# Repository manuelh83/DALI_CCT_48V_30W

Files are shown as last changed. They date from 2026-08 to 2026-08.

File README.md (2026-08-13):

# DALI CCT 48V 30W

DALI-2 DT8 Tunable White LED driver reference design für **48 V DC SELV Eingang** mit bis zu **30 W LED-Leistung**.

Dieses Repository enthält **Hardware- und Firmware-Umfang** inklusive Dokumentation für Entwicklung, Bring-up, Test und Inbetriebnahme.

> ⚠️ **Wichtig:** Referenzdesign für Entwicklungs- und Evaluierungszwecke. Kein automatisch zertifiziertes Endprodukt.

---

## Inhaltsübersicht

- [Projektüberblick](#projektüberblick)
- [Systemarchitektur](#systemarchitektur)
- [Repository-Struktur](#repository-struktur)
- [Hardware-Umfang](#hardware-umfang)
- [Software/Firmware-Umfang](#softwarefirmware-umfang)
- [Toolchain & Voraussetzungen](#toolchain--voraussetzungen)
- [Build & Flash (Firmware)](#build--flash-firmware)
- [Inbetriebnahme (HowTo)](#inbetriebnahme-howto)
- [Test & Verifikation](#test--verifikation)
- [Troubleshooting](#troubleshooting)
- [Sicherheitshinweise](#sicherheitshinweise)
- [Weiterführende Dokumentation](#weiterführende-dokumentation)

---

## Projektüberblick

Das Design realisiert einen DALI-2 DT8 CCT-Treiber (Tunable White) mit:

- **Eingang:** 48 V DC SELV (typischer Bereich 43.2–52.8 V)
- **Ausgang:** gemeinsamer Anodenbus `LED+` und zwei geregelte Kanäle `WW−` / `CW−`
- **Leistung:** bis 30 W
- **Regelung:** kontinuierliche analoge Stromdimmung (0.1–100 %, ohne niederfrequentes PWM-Flackern)
- **Kommunikation:** galvanisch isolierte DALI-2 DT8 Tc Schnittstelle
- **Steuerung:** STM32G031K8T6 + AT24C32E EEPROM

Ziel ist ein robustes Referenzsystem, das als Grundlage für eigene Leuchten-/Treiberentwicklungen dient.

---

## Systemarchitektur

1. **Primärversorgung / Eingangsseite**
   - 48 V SELV Versorgung mit Schutzkonzept für Überspannungsereignisse.

2. **Leistungsteil**
   - 4‑Switch synchroner Buck-Boost (LT8390A) erzeugt geregelten LED-Bus.

3. **LED-Kanalregelung**
   - Zwei lineare Low-Side Konstantstromsenken für Warmweiß/Kaltweiß.

4. **Steuer- und Kommunikationsschicht**
   - STM32G0 übernimmt DALI-Stack, DT8-Verhalten, Kanalmischung, Schutzreaktionen und Persistenz.

5. **Nichtflüchtige Datenhaltung**
   - Externes EEPROM für Parameter, Zustände und Konfigurationswerte.

---

## Repository-Struktur

```text
.
├─ .github/
├─ README.md
├─ firmware/
│  ├─ README.md
│  ├─ docs/
│  │  ├─ README.md
│  │  ├─ build.md
│  │  ├─ api.md
│  │  ├─ dali_implementation.md
│  │  └─ troubleshooting.md
│  ├─ src/
│  ├─ test/
│  └─ lib/
└─ hardware/
   └─ DALI_CCT_48V_30W/
      ├─ README.md
      └─ docs/
         ├─ design-specification.md
         ├─ bom.csv
         ├─ net-class-and-layout-rules.md
         ├─ bring-up-and-test-plan.md
         ├─ open-items-and-risks.md
         └─ firmware-interface.md
```

> Die exakte Dateiliste kann sich weiterentwickeln; für die aktuelle Struktur bitte das Repository-Browsing verwenden.

---

## Hardware-Umfang

Im Pfad `hardware/DALI_CCT_48V_30W/` liegt das vollständige Hardware-Referenzprojekt mit:

- KiCad-Projektdateien (4-Layer PCB, 150 × 60 mm)
- BOM mit Bauteilauswahl und Alternativen
- Spezifikation, Layout-/Netzklassenregeln
- Bring-up-/Testplan
- Risiken & offene Punkte
- Schnittstellendokument zur Firmware-Anbindung

Kernmerkmale:

- 48 V DC SELV Eingang
- 30 W Ausgangsleistung
- gemeinsamer LED+ Bus, getrennte WW/CW Senken
- analoge, kontinuierliche Stromdimmung
- isolierte DALI-2 DT8 Schnittstelle

---

## Software/Firmware-Umfang

Im Pfad `firmware/` befindet sich eine produktionsorientierte Firmware-Basis für **STM32G031** plus host-testbare Logik.

### Enthaltene Bereiche

- `firmware/src/`
  - Hardwareabstraktion/HAL-Wrapper
  - DALI-Kommunikations- und Auswertepfade
  - CCT-/Kanalregel- und Schutzlogik
  - NVM-Zugriffe (EEPROM)
  - Scheduler/Task-Orchestrierung

- `firmware/test/`
  - Host-seitige Unit-Tests für zentrale Protokoll-/Regellogik

- `firmware/docs/`
  - `build.md` (Build/Flash)
  - `api.md` (Modul-/API-Überblick)
  - `dali_implementation.md` (DT8-Verhalten)
  - `troubleshooting.md` (Fehlersuche)

- `firmware/lib/`
  - Integrationshaken für STM32CubeG0 bzw. plattformnahe Komponenten

### Firmware-Funktionsumfang (auf hoher Ebene)

- DALI-2/DT8 Kommandopfad
- Helligkeits- und CCT-bezogene Sollwertverarbeitung
- Kanalmischung WW/CW gemäß Zieltemperatur/Farbanteil
- Schutz- und Fehlerbehandlung (z. B. Grenzwertverletzungen)
- Persistenz relevanter Parameter im EEPROM

---

## Toolchain & Voraussetzungen

### Hardware

- Labornetzteil 48 V DC mit Strombegrenzung
- Last (geeignetes CCT-LED-Setup)
- DALI-Master / DALI-USB Interface
- Multimeter, optional Oszilloskop und Thermalkamera

### Software/Firmware

- ARM GCC Toolchain (oder projektspezifisch dokumentierte Alternative)
- Build-System gemäß `firmware/docs/build.md`
- Flash/Debug-Tool für STM32G0
- Optional: Host-Testumgebung (Compiler + Testframework laut `firmware/test`)

---

## Build & Flash (Firmware)

> Verbindliche Details stehen in `firmware/docs/build.md`.

Typischer Ablauf:

1. Toolchain installieren
2. Firmware-Projekt konfigurieren
3. Build erzeugen (Debug/Release)
4. Binary/ELF auf STM32G031 flashen
5. Serielles Logging / Debug-Schnittstelle prüfen
6. Basisfunktion ohne DALI-Verkehr verifizieren

Empfehlung:

- Erst mit konservativen Strom-/Leistungsgrenzen testen
- Schutzpfade und Fault-Indikationen früh validieren

---

## Inbetriebnahme (HowTo)

Diese Schrittfolge ist als praxisorientierter Leitfaden gedacht und ergänzt den detaillierten Bring-up-Plan unter `hardware/.../docs/bring-up-and-test-plan.md`.

### 1) Sichtprüfung (ohne Spannung)

- Bestückung, Polaritäten, Lötqualität, Steckverbinder prüfen
- Isolations- und Kriechstrecken visuell kontrollieren
- Sicherstellen, dass keine Kurzschlüsse zwischen kritischen Netzen vorliegen

### 2) Erstes Einschalten (ohne LED-Last)

- Labornetzteil auf 48 V setzen, Stromlimit niedrig starten
- Board versorgen und Ruhestrom plausibilisieren
- Grundversorgungen (MCU-Rails, Referenzen) messen

### 3) Firmware laden und Basiskommunikation testen

- Firmware flashen
- MCU startet ohne Fault-Latch
- Debug/Statusausgaben oder definierte Lebenszeichen prüfen

### 4) DALI-Bus anbinden

- DALI-Leitungen korrekt verbinden (Polarität/Buskonzept beachten)
- DALI-Master verbinden
- Erreichbarkeit und Reaktion auf Basisbefehle verifizieren

### 5) LED-Last anschließen

- CCT-Last korrekt an `LED+`, `WW−`, `CW−` anschließen
- Mit niedrigen Sollwerten starten
- Kanalströme messen und plausibilisieren

### 6) Funktionsprüfung CCT/Helligkeit

- Helligkeitsrampe über den vorgesehenen Bereich prüfen
- CCT-Änderungen (warm ↔ kalt) beobachten
- Übergänge auf Stabilität/Flickerfreiheit prüfen

### 7) Schutz- und Grenzfalltests

- Grenzbereiche in kontrollierter Form anfahren
- Verifikation von Fault-Reaktionen und Recovery-Strategie
- Sicherstellen, dass keine unzulässige Überlastung entsteht

### 8) Thermik-Check unter Dauerlast

- Erwärmung an kritischen Komponenten überwachen
- Betriebspunkt nur freigeben, wenn thermisch stabil

### 9) Persistenz/NVM prüfen

- Relevante Parameter ändern
- Power-Cycle durchführen
- Wiederherstellung aus EEPROM verifizieren

### 10) Abschlussfreigabe (Prototyp)

- Dokumentierte Sollwerte/Abnahmekriterien abgleichen
- Messergebnisse protokollieren

---

## Test & Verifikation

Empfohlene Reihenfolge:

1. Host-Unit-Tests (`firmware/test`)
2. Kommunikationspfad DALI/DT8
3. Kanalregelung und CCT-Verhalten
4. Fault-Injection / Schutzpfade
5. Thermik- und Dauerlasttests

Für formale Kriterien den hardwareseitigen Bring-up/Testplan verwenden.

---

## Troubleshooting

- Kein Start nach Flash:
  - Takt-/Reset-Konfiguration und Build-Target prüfen
  - Versorgung und Brownout-Bedingungen verifizieren

- DALI ohne Reaktion:
  - Busverdrahtung und Master-Konfiguration kontrollieren
  - Implementierte DT8-Kommandos mit `firmware/docs/dali_implementation.md` abgleichen

- Instabiles Dimmverhalten:
  - Sollwertgrenzen und Kalibrierungen prüfen
  - Kanalströme und Lastkompatibilität messen

- Unerwartete Faults:
  - Schutzschwellen/Telemetrie sichten
  - Schritte aus `firmware/docs/troubleshooting.md` anwenden

---

## Sicherheitshinweise

- Nur durch qualifiziertes Fachpersonal in geeigneter Laborumgebung betreiben
- Strombegrenzung beim Erststart immer aktivieren
- Thermische Risiken bei Dauerlast berücksichtigen
- Isolations- und EMV-Anforderungen für Zielprodukt separat validieren

---

## Weiterführende Dokumentation

### Root

- `README.md` (dieses Dokument)

### Hardware

- `hardware/DALI_CCT_48V_30W/README.md`
- `hardware/DALI_CCT_48V_30W/docs/design-specification.md`
- `hardware/DALI_CCT_48V_30W/docs/bom.csv`
- `hardware/DALI_CCT_48V_30W/docs/net-class-and-layout-rules.md`
- `hardware/DALI_CCT_48V_30W/docs/bring-up-and-test-plan.md`
- `hardware/DALI_CCT_48V_30W/docs/open-items-and-risks.md`
- `hardware/DALI_CCT_48V_30W/docs/firmware-interface.md`

### Firmware

- `firmware/README.md`
- `firmware/docs/README.md`
- `firmware/docs/build.md`
- `firmware/docs/api.md`
- `firmware/docs/dali_implementation.md`
- `firmware/docs/troubleshooting.md`

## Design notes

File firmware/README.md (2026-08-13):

# Firmware

Production-oriented STM32G031 firmware skeleton and host-testable logic for the DALI CCT 48V 30W reference design.

## Contents

- `src/` – HAL wrappers, DALI stack, control logic, NVM, protection, scheduler
- `test/` – host-side unit tests for the critical control and parser logic
- `docs/` – build, API, DALI, and troubleshooting notes
- `lib/` – optional STM32CubeG0 integration hook

See `docs/build.md` for build and flash instructions.

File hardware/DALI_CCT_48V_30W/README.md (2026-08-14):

# DALI CCT 48V 30W – Hardware Reference Design Rev A

> **⚠️ WARNING – REFERENCE DESIGN ONLY**
>
> This is an engineering reference design. It **must not be manufactured or deployed** without:
> - Independent schematic review and simulation
> - Prototype build and validation
> - Thermal design verification
> - EMC testing per applicable standards (e.g., EN 55015 / CISPR 15)
> - Electrical safety assessment (e.g., IEC 62368-1 / EN 61347-2-13)
> - DALI-2 conformance testing (DIIA/DALI Alliance test suites)
> - All applicable regulatory approvals for target market

---

## Project Scope

A production-oriented KiCad 8+ reference design for a **48 V SELV, 30 W maximum, DALI-2 DT8 Tunable White LED driver** with the following key features:

| Parameter | Value |
|---|---|
| Input voltage | 48 V DC SELV, operating range 43.2–52.8 V |
| Transient protection | Designed for short transients up to 60 V |
| LED output | 30 W max total; three terminals LED+, WW−, CW− (common-anode CCT) |
| LED string range | 28–42 V per channel |
| Max current per channel | 700 mA (firmware limits total power to ≤30 W) |
| Dimming | 0.1–100%, continuous/analog current control, no low-frequency PWM |
| DALI | DALI-2 control gear, DT8 Tc Tunable White (IEC 62386-101/-102/-209) |
| PCB size | 150 × 60 mm, 4 layers |
| Component height | ≤30 mm |
| Thermal | Aluminium enclosure coupling via B.Cu thermal zone + thermal vias |

---

## Architecture

```
48V DC SELV IN
    │
    ├── [J1] 48V_IN+/48V_IN− screw terminal (5.08mm)
    │
    ├── BLOCK 1: Input Protection
    │     F1: Fuse 1A slow-blow
    │     D1: P-channel MOSFET reverse-polarity protection
    │     TV1: TVS 60V/600W bidirectional clamp
    │     C1,C2: 100µF/63V bulk caps + EMI filter
    │
    ├── BLOCK 4: Auxiliary Supply 48V→5V→3.3V
    │     U_AUX1: LMR16006YDDAR synchronous buck (5V/600mA)
    │     U_LDO: AP2112K-3.3 LDO (3.3V/600mA)
    │
    ├── BLOCK 2: 4-Switch Synchronous Buck-Boost LED Bus
    │     U_BB: LT8390A controller, Q1-Q4 MOSFETs, L2 47µH
    │     Output: LED_BUS+ nominally 44V
    │     → [J3-pin1] LED+ (common anode)
    │
    ├── BLOCK 3: Two Linear Low-Side Current Sinks
    │     Q_WW + R_SENSE_WW + U_CS_WW (OPA2333) → [J3-pin2] WW−
    │     Q_CW + R_SENSE_CW + U_CS_CW (OPA2333) → [J3-pin3] CW−
    │     Hardware OCP via LM393 comparator (threshold ~900mA)
    │     Analog current setpoint from MCU DAC (MCP4728 12-bit I2C)
    │
    ├── BLOCK 5: MCU, NVM, SWD
    │     U_MCU: STM32G031K8T6 (ARM Cortex-M0+, 64KB flash)
    │     U_EEP: AT24C32E I2C EEPROM (DALI NVM)
    │     U_DAC: MCP4728 12-bit quad DAC (current setpoints)
    │     [J4] SWD programming header (1.27mm)
    │
    └── BLOCK 6: Galvanically Isolated DALI Interface
          Isolation goal: 2.5kVrms (subject to safety standard review)
          U_DALI: NXP UBA2015 or optocoupler-based frontend
          D_ESD: PRTR5V0U2X ESD protection
          [J2] DALI_A/DALI_B screw terminal (5.08mm)
```

### Power Architecture Note

This design uses a **common regulated 4-switch synchronous buck-boost LED bus** (nominally 44 V) followed by **two independently controlled, linear low-side constant-current sinks** (WW and CW). This is the correct representation: a single regulated voltage bus with common LED anode, and individual current control on the low side per channel.

---

## Opening in KiCad 8+

1. Open KiCad 8.0 or later.
2. File → Open Project → select `DALI_CCT_48V_30W.kicad_pro`.
3. Open the schematic editor: `DALI_CCT_48V_30W.kicad_sch`.
4. Open the PCB editor: `DALI_CCT_48V_30W.kicad_pcb`.

### ERC/DRC Status (Rev A.1)

**Schematic (`.kicad_sch`):** All KiCad symbol instances required for the current reference design are present, and U_BB now uses the exact project-local `AnalogDevices:LT8390AIFE` 28-pin symbol instead of the generic `Device:IC`. The schematic netlist is still intended to be verified with KiCad 8 ERC after opening the project locally. See OI-011 in `docs/open-items-and-risks.md` for full details.

**PCB (`.kicad_pcb`):**
- Board outline, mounting holes, and connector footprints defined (Rev A)
- **Rev A.1 additions**: D2PAK footprints for Q_WW and Q_CW with 9 thermal vias each and 20×20mm B.Cu thermal pour zones
- Isolation barrier silkscreen updated: `ISO BARRIER: CLR>=2mm / CRG>=5mm / ZONE=8mm (IEC 62368-1:2018)`
- Full component placement and routing requires KiCad 8 GUI after netlist import from schematic

**Intentional open items / known DRC status:**
- Routing is incomplete; ratsnest will show unconnected nets after netlist import
- Q_WW/Q_CW D2PAK gate pads are unconnected pending netlist import (expected)
- Other complex ICs still use generic `Device:IC` symbols — replace them with exact library symbols in follow-up cleanup work
- Full DRC pass (including creepage/clearance checks for `DALI_ISO` net class) requires complete routing

**Normative DRC rules (`.kicad_dru`):**
- `DALI_ISO` class: clearance ≥ 2.0mm (IEC 62368-1:2018 Table G.8), keepout zone ≥ 8mm (satisfies creepage ≥ 5.0mm with margin)
- `PWR_HV` (48V): clearance ≥ 0.5mm, track width ≥ 2.0mm
- `PWR_LED` (LED bus): track width ≥ 1.5mm
- `KELVIN` (sense): track width ≤ 0.2mm, Kelvin-pair routing required

See `docs/open-items-and-risks.md` for full list of open items (OI-011: RESOLVED, OI-012: IN PROGRESS).

---

## Directory Structure

```
hardware/DALI_CCT_48V_30W/
├── DALI_CCT_48V_30W.kicad_pro      KiCad 8 project file
├── DALI_CCT_48V_30W.kicad_sch      Schematic (functional block descriptions + net list)
├── DALI_CCT_48V_30W.kicad_pcb      PCB layout (board outline, layer setup, key placements)
├── README.md                        This file
└── docs/
    ├── design-specification.md      Full electrical specification
    ├── bom.csv                      Bill of Materials
    ├── net-class-and-layout-rules.md  PCB routing rules and net classes
    ├── bring-up-and-test-plan.md    Prototype bring-up sequence
    ├── open-items-and-risks.md      Open design items and risks
    └── firmware-interface.md        MCU/firmware interface documentation
```

---

## Practical Power and Current Limits

| Condition | WW Current | CW Current | Total Power |
|---|---|---|---|
| Full warm white (2700K) | 700 mA | 0 mA | ≤28 W at 40V LED |
| Full cool white (6500K) | 0 mA | 700 mA | ≤28 W at 40V LED |
| Neutral white (4000K) | ~350 mA | ~350 mA | ≤25 W typical |
| Firmware hard limit | | | 30 W total |
| Hardware OCP per channel | 1.05 A | 1.05 A | — |

The firmware enforces `P_total = V_LED_BUS × (I_WW + I_CW) ≤ 30 W` using ADC-measured bus voltage and DAC-controlled current.

---

## License / Disclaimer

This reference design is provided as-is for engineering reference purposes only. No warranty of fitness for any purpose is expressed or implied. The designer and contributors accept no liability for any direct or indirect damages arising from use of this material. All component datasheets, safety standards, and certification requirements must be independently verified by a qualified engineer before manufacture.

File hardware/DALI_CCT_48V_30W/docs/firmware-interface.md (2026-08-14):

# Firmware Interface Documentation – DALI CCT 48V 30W Rev A

---

## 1. Overview

The firmware runs on a STM32G031K8T6 (ARM Cortex-M0+, 64MHz, 64KB flash, 8KB SRAM). It implements:

- DALI-2 control gear behavior (IEC 62386-101 and -102)
- DALI-2 Device Type 8 – Tunable White Tc (IEC 62386-209)
- Analog current control of two LED channels (WW and CW) via I2C DAC (MCP4728)
- NVM management via I2C EEPROM (AT24C32E)
- Hardware fault monitoring and protection
- Thermal management via NTC ADC

---

## 2. MCU Pin Roles

| Pin | Direction | Net | Function | Notes |
|---|---|---|---|---|
| PA0 | ADC in | ADC_NTC | NTC temperature sense | 12-bit ADC; divider: 100kΩ pull-up to 3.3V, NTC to GND |
| PA1 | ADC in | ADC_VIN | 48V input voltage monitor | Divider: 750kΩ / 38.3kΩ → ~0.048×Vin |
| PA2 | ADC in | ADC_VBUS | LED bus voltage monitor | Divider: 750kΩ / 38.3kΩ → ~0.048×Vbus |
| PA4 | DAC out | MCU_DAC_WW | WW current setpoint (backup) | 12-bit DAC; only used if MCP4728 I2C fails |
| PA5 | DAC out | MCU_DAC_CW | CW current setpoint (backup) | 12-bit DAC backup |
| PA6 | GPIO in | OCP_WW | WW over-current latch signal | Active-high from LM393 comparator |
| PA7 | GPIO in | OCP_CW | CW over-current latch signal | Active-high from LM393 comparator |
| PA9 | USART1_TX | DALI_TX | DALI transmit (to optocoupler) | Half-duplex; open-drain recommended |
| PA10 | USART1_RX | DALI_RX | DALI receive (from optocoupler) | Pull-up to 3.3V |
| PA13 | SWD | SWDIO | SWD data line | Programming and debug |
| PA14 | SWD | SWDCLK | SWD clock | Programming and debug |
| PB0 | GPIO out | EN_WW | WW channel enable | Active-high; drives NAND latch for Q_WW gate |
| PB1 | GPIO out | EN_CW | CW channel enable | Active-high |
| PB3 | GPIO out | LED_STATUS | Green status LED | Active-high; 1kΩ series |
| PB4 | GPIO out | LED_FAULT | Red fault LED | Active-high; 1kΩ series |
| PB6 | I2C1_SCL | I2C_SCL | I2C bus clock | 400kHz; 4.7kΩ pull-up to 3.3V |
| PB7 | I2C1_SDA | I2C_SDA | I2C bus data | 400kHz; 4.7kΩ pull-up to 3.3V |
| PB8 | GPIO out | BB_SHDN | Buck-boost enable/shutdown | Active-low shutdown; 100kΩ pull-up to 5V_AUX keeps converter enabled when MCU is high-Z |
| NRST | Reset | NRST | Hardware reset | 100nF to GND; external reset pin |

### I2C Device Addresses

| Device | I2C Address | Function |
|---|---|---|
| MCP4728 | 0x60 | 12-bit quad DAC for WW/CW setpoints |
| AT24C32E | 0x50 | EEPROM for DALI NVM |

**LT8390A hardware-set analog pins**

`RT`, `SLOPE`, `ITH/COMP`, `CS+`, `CS-`, and `FB` are not firmware-controlled. Their values are fixed in hardware by `R_RT`, `R_SLOPE`, `C_ITH`, `R_ITH`, `C_ITH2`, `R_FB1`, and `R_FB2`. Firmware only asserts `BB_SHDN`, monitors `ADC_VIN` / `ADC_VBUS`, and reacts to resulting faults.

---

## 3. DALI Protocol Implementation

### 3.1 Standards Targeted

| Standard | Scope |
|---|---|
| IEC 62386-101 | DALI-2 general requirements, electrical interface |
| IEC 62386-102 | Control gear (slave) general behavior |
| IEC 62386-209 | Device type 8: colour control (Tunable White Tc) |

**Note**: DALI-2 certification is not claimed. The firmware is designed to follow the above standards but must pass official DALI Alliance test suites before the product may be labeled as DALI-2 certified.

### 3.2 DALI Physical Layer

- Baud rate: 1200 baud (Manchester encoding)
- Bit period: 833µs; half-bit period: 416µs
- Bus voltage: 9.5V–22.5V (sourced by DALI master)
- Transmission: MCU drives optocoupler TX open-collector pull-down
- Reception: optocoupler RX drives MCU PA10 (USART1_RX)
- USART configuration: 1200 baud, 8N1, single-wire half-duplex mode; Manchester coding implemented in software via bit-banging on TIM1 or via hardware USART in Manchester mode (STM32G0 supports hardware Manchester)

### 3.3 DALI Device Behavior (IEC 62386-102)

The firmware must implement the following command sets:

**Addressing and Initialization**
- INITIALISE, RANDOMISE, COMPARE, WITHDRAW, SEARCH ADDRESS, PROGRAM SHORT ADDRESS, VERIFY SHORT ADDRESS, QUERY SHORT ADDRESS
- Support for broadcast, group, and individual short address

**Arc Power Level Control**
- DAPC (Direct Arc Power Control): 0–254 arc-power levels
- ON, OFF, RECALL MAX LEVEL, RECALL MIN LEVEL, STEP UP, STEP DOWN
- GO TO SCENE (16 scenes: 0–15)
- SET MAX LEVEL, SET MIN LEVEL, SET SYSTEM FAILURE LEVEL, SET POWER ON LEVEL
- Fade: FADE TIME (0–15), FADE RATE (1–15), NON-FADE TIME
- QUERY commands: QUERY STATUS, QUERY CONTROL GEAR PRESENT, QUERY LIGHT SOURCE, QUERY ACTUAL LEVEL, QUERY MAX/MIN/POWER-ON/SYSTEM-FAILURE LEVEL, QUERY FADE TIME/RATE, QUERY SCENE LEVEL

**DALI Arc-Power Dimming Curve**:
```
If arc_power_level == 0: output = OFF (current = 0)
If arc_power_level == 1: output = MIN_LEVEL (firmware default: ~0.1% = ~0.6mA at 600mA FSR)
If arc_power_level == 254: output = MAX_LEVEL (firmware default: 100% = full current)
Physical_current = max_current × (10 ^ ((arc_power_level - 254) / 253 × log10(min/max)))
```
The logarithmic curve maps 254 steps across a configurable dimming range.

### 3.4 DT8 Tc Implementation (IEC 62386-209)

**Colour Temperature Control**

Commands implemented:
- SET COLOUR TEMPERATURE TC (value in mirek = 1,000,000 / Kelvin)
- QUERY COLOUR VALUE: Colour Temperature TC (current and target)
- QUERY COLOUR TEMPERATURE TC COOLEST, QUERY COLOUR TEMPERATURE TC WARMEST
- SET COLOUR TEMPERATURE TC COOL BOUND, SET COLOUR TEMPERATURE TC WARM BOUND

Default Tc range: 153 mirek (6536K) to 370 mirek (2703K). Configurable via NVM.

**WW/CW Mixing Algorithm**

Given a target colour temperature Tc_target and a total current I_total derived from arc-power level:

```c
// Normalise: 0.0 = coolest (Tc_cool), 1.0 = warmest (Tc_warm)
float alpha = (Tc_target - Tc_cool) / (Tc_warm - Tc_cool);
alpha = clamp(alpha, 0.0f, 1.0f);

// Linear mix (default; replace with calibrated table for accuracy — see OI-009)
float I_WW = I_total * alpha;
float I_CW = I_total * (1.0f - alpha);

// Power limit enforcement
float v_bus = adc_to_volts(ADC_VBUS);
float p_est = v_bus * (I_WW + I_CW);
if (p_est > P_MAX_LIMIT) {
    float scale = P_MAX_LIMIT / p_est;
    I_WW *= scale;
    I_CW *= scale;
}
```

**Calibrated mixing table (production implementation):**

For accurate CCT control, the linear approximation above should be replaced with a calibrated lookup table derived from photometric measurement of the actual LED module. The calibration procedure is:

1. Measure CIE 1931 (x, y) chromaticity of WW LED at 100 %, 50 %, 10 % current; record lm/mA.
2. Measure CIE 1931 (x, y) chromaticity of CW LED at 100 %, 50 %, 10 % current; record lm/mA.
3. For each target Tc in the operating range (e.g., every 100 mirek), solve the 2-primary mixing equations:

```
x_mix = (I_WW × lm_WW × x_WW + I_CW × lm_CW × x_CW) / (I_WW × lm_WW + I_CW × lm_CW)
y_mix = (I_WW × lm_WW × y_WW + I_CW × lm_CW × y_CW) / (I_WW × lm_WW + I_CW × lm_CW)
```

   Subject to: x_mix, y_mix lie on the Planckian locus at the target Tc.

4. Build a lookup table: `uint16_t ww_ratio_table[TC_STEPS]` where the value represents I_WW / I_total × 4095.
5. Store lookup table in MCU flash. At runtime, interpolate linearly between table entries.
6. Verify gamut: confirm the LED pair can achieve all Tc values in [Tc_cool, Tc_warm]; document the achievable gamut.

```c
// Production mixing with lookup table
uint16_t idx     = tc_to_table_index(Tc_target);     // mirek → table index
float    ratio   = ww_ratio_table[idx] / 4095.0f;    // WW fraction
float    I_WW    = I_total * ratio;
float    I_CW    = I_total * (1.0f - ratio);
```

**Note**: Linear interpolation assumes equal efficacy per mA for WW and CW. Real LEDs differ in lumens/mA and correlated colour temperature vs. current. The calibrated lookup table is recommended for production.

---

## 4. NVM Behavior (EEPROM AT24C32E)

### 4.1 DALI NVM Requirements

The following parameters must be stored in non-volatile memory per IEC 62386-102/-209:

| Parameter | Size | Default |
|---|---|---|
| Short address | 1 byte | 0xFF (unassigned) |
| Group membership (groups 0–15) | 2 bytes | 0x0000 |
| Scene table: dim levels (16 × 1 byte) | 16 bytes | 0xFF (MASK = no action) |
| Scene table: CCT values (16 × 2 bytes) | 32 bytes | 0x0000 (no-change) |
| MAX LEVEL | 1 byte | 0xFE (254) |
| MIN LEVEL | 1 byte | 0x01 (1) |
| POWER ON LEVEL | 1 byte | 0xFF (LAST ACTIVE) |
| SYSTEM FAILURE LEVEL | 1 byte | 0xFF (LAST ACTIVE) |
| FADE TIME | 1 byte | 0 (no fade) |
| FADE RATE | 1 byte | 7 |
| Physical min level | 1 byte | 0x01 |
| Device type | 1 byte | 0x08 (DT8) |
| Tc cool bound (mirek) | 2 bytes | 153 |
| Tc warm bound (mirek) | 2 bytes | 370 |
| Last active arc-power level | 1 byte | 0xFE |
| Last active Tc (mirek) | 2 bytes | 261 (3831K neutral) |

Total static NVM: ~70 bytes. With wear-leveling overhead, allocate 512 bytes minimum.

### 4.2 Wear-Leveling Strategy

- Static DALI config (address, groups, scenes): written only on explicit DALI write commands. Expected: < 1000 writes per lifetime. No wear-leveling needed; write to fixed page.
- Dynamic state (last arc-power, last Tc): written on state change after a 5-second debounce timer. Circular buffer of 64 slots × 4 bytes = 256 bytes. Rotates write pointer on each write.
  - At 1M page-write endurance per slot × 64 slots = 64M writes before wear-out
  - At worst case 10 writes/hour × 8760 hours/year = 87,600 writes/year → >730 years effective life
- Firmware reads back NVM after write and verifies correctness (read-after-write check).

### 4.3 Power-On State Restoration

On power-up:
1. Read POWER ON LEVEL from NVM.
2. If POWER ON LEVEL == 0xFF (LAST ACTIVE): read last-active dim level and Tc from circular buffer.
3. Ramp outputs from 0 to target values over FADE TIME (if non-zero).
4. If NVM read fails (I2C error, CRC fail): use firmware-compiled defaults (50% dim, 4000K).

On DALI bus loss (no valid DALI frame received for >500ms):
- Maintain current output without change.
- Set "LAMP FAILURE" status bit (query will return it cleared once bus resumes).

---

## 5. Brightness and CCT to WW/CW Current Mapping

### 5.1 Current Scale

- Maximum hardware current per channel: 900 mA (OCP threshold)
- Maximum firmware-enforced current per channel: **600 mA** (firmware constant `I_MAX = 600mA`)
- Maximum total firmware-enforced power: firmware enforces P_total ≤ 28W
- DAC full scale: MCP4728 = 4096 counts → 0–1.0V → 0–600mA through op-amp control loop

```
DAC_WW_code = round(I_WW_target / I_MAX * 4095)
DAC_CW_code = round(I_CW_target / I_MAX * 4095)
```

Where `I_MAX = 600mA` (firmware constant; hardware OCP set to 900mA absolute limit).

### 5.2 Power Limiting

The bus voltage is fixed at 44 V (LT8390A setpoint; not adjusted by firmware). Power limiting is enforced by capping total current:

```c
// Fixed bus voltage: no ADC_VBUS monitoring for adaptive control
const float V_BUS_FIXED = 44.0f;   // V; fixed by hardware feedback divider
const float P_MAX_LIMIT = 28.0f;   // W; 28W leaves headroom below 30W spec

float p_est = V_BUS_FIXED * (i_ww_set + i_cw_set);
if (p_est > P_MAX_LIMIT) {
    float scale = P_MAX_LIMIT / p_est;
    i_ww_set *= scale;
    i_cw_set *= scale;
}
```

ADC_VBUS (PA2) is still read for monitoring and fault detection (over/under-voltage), but is **not** used to adjust the bus voltage setpoint. The LT8390A feedback divider fixes V_bus at 44 V.

### 5.3 Fade Implementation

DALI fade timer runs at 100Hz (every 10ms). On each tick during a fade:

```
target_arc = commanded arc-power level
target_tc  = commanded Tc

// Dimming fade
if (current_arc != target_arc):
    step = fade_step_per_tick(fade_time)    // from DALI fade table
    current_arc = approach(current_arc, target_arc, step)

// Tc fade (simultaneous with dimming fade)
if (current_tc != target_tc):
    tc_step = fade_step_per_tick(fade_time)
    current_tc = approach(current_tc, target_tc, tc_step)

// Compute and update DAC
update_currents(current_arc, current_tc)
```

Fade occurs simultaneously for arc-power and colour temperature.

### 5.4 Minimum Dimming Level Analysis (OI-010)

The specification requires 0.1 % dimming (1:1000 ratio), corresponding to 0.7 mA at 700 mA full scale.

**Error budget at minimum current:**

| Error source | Value | Current error at 100 mΩ sense |
|---|---|---|
| OPA2333 input offset (max, 25°C) | 10 µV | 0.10 mA |
| OPA2333 input offset drift (max, −40 to +85°C) | 0.05 µV/°C × 60°C | +0.03 mA |
| MCP4728 zero-code output (max) | 0.5 mV | 5.0 mA |
| MCP4728 INL (max, 12-bit) | 2 LSB = 0.488 mV | 0.49 mA |
| PCB leakage / sense resistor offset | < 10 µV | < 0.10 mA |
| **Total (worst-case, RSS)** | | **≈ 5.1 mA** |

The dominant error is the **MCP4728 zero-code offset** (~0.5 mV at DAC output = 0). The offset is trimmed per device; typical offset is < 0.1 mV.

**Achievable minimum current (typical):** 0.7 mA (MCP4728 typical offset 0.1 mV → 1 mA total error; firmware zeros DAC and cuts EN_WW/EN_CW to achieve true off below 0.5 mA).

**Mitigation for worst-case parts:**
1. **Firmware offset compensation**: At start-up, characterise per-unit DAC offset by measuring V_SENSE at DAC code 0 with channel enabled; store correction in NVM; subtract from all DAC codes.
2. **Dual-range option (if 0.1 % not achievable)**: Below arc-power level 10 (≈ 1 %), enable PWM blanking: pulse EN_WW/EN_CW at 1 kHz with duty cycle proportional to dim level. This extends effective range to 1:10 000. Ensure PWM frequency ≥ 1 kHz to avoid visible flicker.
3. **Sense resistor increase**: Replacing 100 mΩ with 200 mΩ halves the offset-referred error at cost of 2× higher minimum voltage drop (140 mV at 700 mA); acceptable if MOSFET Vds headroom permits.

**Recommendation**: Implement firmware offset compensation (option 1) first; evaluate on prototype. Dual-range PWM (option 2) is a fallback if offset compensation is insufficient at temperature extremes.

---

## 6. Fault Handling

### 6.1 Fault Types

| Fault | Detection | Action | Recovery |
|---|---|---|---|
| OCP WW channel | PA6 high (LM393) | EN_WW = 0 immediately; log fault; set LAMP FAILURE | MCU resets after 100ms; 3 retry attempts; permanent off after 3 fails |
| OCP CW channel | PA7 high (LM393) | EN_CW = 0 immediately; log fault | Same as WW |
| Over-temperature warn (70°C) | ADC_NTC > threshold | Reduce I_MAX by 20% (600mA → 480mA); set LED_FAULT blink pattern | Auto-clear when temp < 60°C |
| Over-temperature shutdown (85°C) | ADC_NTC > threshold | EN_WW = 0; EN_CW = 0; BB_SHDN = 0; LED_FAULT solid | Auto-restart when temp < 75°C |
| Input under-voltage (<43V) | ADC_VIN < threshold | BB_SHDN = 0 (shutdown converter); channels off | Auto-enable when Vin > 44V |
| Input over-voltage (>55V) | ADC_VIN > threshold | BB_SHDN = 0 immediately | Auto-enable when Vin < 53V |
| I2C DAC failure | I2C NACK from MCP4728 | Switch to MCU internal DAC (PA4/PA5); log fault | Retry I2C init on next power cycle |
| NVM read failure | I2C NACK or CRC fail | Use defaults; log fault; LED_FAULT blink | Retry on power cycle |

#### NTC-based Current Limiting (Thermal Management)

The NTC thermistor (NTC1, 100kΩ B3950, mounted near Q_WW/Q_CW on B.Cu thermal pour) is read via ADC_NTC (PA0) every 500 ms. Current limiting is purely **current-based** – the bus voltage (44 V fixed) is never adjusted by firmware.

```c
// Thermal current-limiting state machine (no Vbus modification)
float pcb_temp_c = ntc_adc_to_celsius(adc_read(ADC_NTC));

if (pcb_temp_c >= NTC_SHUTDOWN_TEMP) {       // 85°C
    i_max_thermal = 0.0f;                    // total shutdown
    set_fault(FAULT_OVERTEMP_SHUTDOWN);
} else if (pcb_temp_c >= NTC_WARN_TEMP) {    // 70°C
    i_max_thermal = I_MAX_NOMINAL * 0.80f;   // 600mA × 0.80 = 480mA
    set_fault(FAULT_OVERTEMP_WARN);
} else if (pcb_temp_c < NTC_WARN_TEMP - NTC_HYSTERESIS) {  // < 60°C
    i_max_thermal = I_MAX_NOMINAL;           // 600mA; normal operation
    clear_fault(FAULT_OVERTEMP_WARN);
}

// Apply thermal limit before DAC update
float i_ww_clamped = fminf(i_ww_set, i_max_thermal);
float i_cw_clamped = fminf(i_cw_set, i_max_thermal);
```

**Key constants:**
- `I_MAX_NOMINAL = 600mA` – firmware maximum under normal conditions
- `NTC_WARN_TEMP = 70°C` – triggers 20% current reduction
- `NTC_SHUTDOWN_TEMP = 85°C` – triggers full shutdown
- `NTC_HYSTERESIS = 10°C` – re-enable hysteresis (warn clears at 60°C, shutdown at 75°C)

**Important**: This is purely current-limiting. The firmware does **not** read `ADC_VBUS` to adjust the LT8390A output voltage. The bus remains at a fixed 44 V at all times.

### 6.2 DALI Fault Reporting

The DALI QUERY STATUS command returns:
- Bit 0: Ballast failure (set if hardware fault prevents operation)
- Bit 1: Lamp failure (set if LED OCP latch is active)
- Bit 2: Lamp arc power on (set if arc-power > 0)
- Bit 3: Limit error (set if requested level was clipped by MIN or MAX)
- Bit 4: Fade running
- Bit 5: Reset state (set after power-on before any DALI command received)
- Bit 6: Missing short address
- Bit 7: Power failure (set after unexpected power-off detected via NVM)

---

## 7. Test and Programming Interface

### 7.1 SWD Interface (J4)

| Pin | Signal | Notes |
|---|---|---|
| 1 | GND | Reference |
| 2 | SWDIO | SWD data; also TP_SWDIO test pad |
| 3 | SWDCLK | SWD clock; also TP_SWDCLK test pad |
| 4 | 3.3V | Target VCC (powered by board) |

Compatible debuggers: ST-LINK V2, ST-LINK V3, J-Link, CMSIS-DAP.
Connector: 1.27mm pitch 4-pin (e.g., Samtec FTSH-104-01-L-DV) or solder pads.

### 7.2 Factory Test Procedure

1. Connect ST-LINK to J4.
2. Program production firmware binary.
3. Run built-in self-test (BIST) via UART or SWD:
   - Verify I2C DAC responds (MCP4728 at 0x60)
   - Verify EEPROM responds (AT24C32E at 0x50)
   - Verify ADC reads (NTC, VIN, VBUS) within range
   - Verify DALI TX/RX loopback (if test loopback jumper installed)
4. Program DALI factory defaults to EEPROM.
5. Disconnect ST-LINK.

### 7.3 BOOT0 Solder Jumper (SJ1)

- SJ1 open (default): BOOT0 = GND → boot from flash (normal operation)
- SJ1 closed: BOOT0 = VCC → boot from system memory (STM32 USB DFU bootloader)
- DFU mode allows firmware update via USB (if USB physical connector added) or UART bootloader via PA9/PA10

### 7.4 Firmware Build Environment

Recommended toolchain:
- Compiler: GCC ARM Embedded (arm-none-eabi-gcc), version 12 or later
- IDE: STM32CubeIDE or Visual Studio Code with Cortex-Debug extension
- HAL: STM32CubeG0 HAL library
- Build system: CMake or STM32CubeIDE project
- DALI stack: custom implementation or adapt open-source DALI library (verify license compatibility)
  - Reference: DALI-2 library for STM32 (community projects exist; verify completeness for DT8 Tc)

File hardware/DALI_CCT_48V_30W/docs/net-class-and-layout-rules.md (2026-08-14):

# Net Classes and Layout Rules

## PCB Stackup

| Layer | Name | Weight | Role |
|---|---|---|---|
| 1 (top) | F.Cu | 35µm (1oz) | Signal, DALI isolated domain, logic routing |
| 2 | In1.Cu | 35µm (1oz) | Uninterrupted GND reference plane |
| 3 | In2.Cu | 35µm (1oz) | Inner signal/power routing |
| 4 (bottom) | B.Cu | 70µm (2oz) | Power/thermal; couples to aluminium enclosure |

Board material: FR4, Tg ≥ 150°C. Thickness: 1.6mm.

---

## Net Classes

### PWR_HV (48V Input Power)

Applies to nets matching: `48V*`, `PGND*`

| Rule | Value | Rationale |
|---|---|---|
| Minimum track width | 2.0 mm | 1.5A continuous; temperature rise < 10°C in 1oz Cu |
| Minimum clearance | 0.5 mm | 60V SELV + creepage margin |
| Via drill | 0.6 mm | Sufficient for power |
| Via annular ring | 0.3 mm | Minimum for outer layers |
| Differential pair gap | N/A | Not differential |

### PWR_LED (LED Bus and Channels)

Applies to nets matching: `LED*`, `LED_BUS*`, `WW-`, `CW-`

| Rule | Value | Rationale |
|---|---|---|
| Minimum track width | 1.5 mm | 600mA peak per channel; temperature rise < 10°C |
| Minimum clearance | 0.3 mm | 44V + margin |
| Via drill | 0.5 mm | Power via |
| Via annular ring | 0.25 mm | Standard |

### DALI_ISO (DALI Isolated Domain)

Applies to nets matching: `DALI*`

| Rule | Value | Rationale |
|---|---|---|
| Minimum track width | 0.5 mm | Low current; wide for robustness |
| Minimum clearance | 0.5 mm | Within isolated domain |
| **Clearance to non-isolated domain (air)** | **2.0 mm minimum** | Normatively derived; see §Isolation Note |
| **Creepage to non-isolated domain (surface)** | **5.0 mm minimum** | Normatively derived; see §Isolation Note |
| **PCB keepout zone (implemented)** | **8.0 mm** | Exceeds minimums; manufacturing tolerance and conformal coating margin |
| Via drill | 0.4 mm | Standard signal via |

**Isolation Note – Normative Derivation (IEC 62368-1:2018)**

Design conditions assumed for the galvanic DALI isolation barrier:
- Isolation class: **Reinforced insulation** (single barrier providing protection equivalent to double insulation; required for DALI bus voltage vs. SELV 48V side)
- Working voltage (non-isolated side): **63 V** (next standard step above 52.8 V max operating; 60 V peak transient)
- Pollution degree: **2** (light condensation possible; indoor product)
- Overvoltage category (SELV supply input): **OVC II** (equipment connected to fixed installation, transient overvoltage 800 V per IEC 62368-1 Annex G)
- PCB material group: **IIIa** (FR4; CTI 100–175)

**Derived minimum clearance** (IEC 62368-1:2018, Table G.8 – reinforced insulation, OVC II, 800 V impulse):

```
Impulse withstand voltage for OVC II, 63V working = 800 V (IEC 62368-1 Table G.1)
Reinforced clearance (Table G.8, 800V impulse)   = 0.8 mm × 2 = 1.6 mm
→ Round up to manufacturing minimum:               2.0 mm
```

**Derived minimum creepage** (IEC 62368-1:2018, Table G.12 – reinforced insulation, Material Group IIIa, PD2):

```
Basic creepage (Table G.12, 63V, IIIa, PD2)      = 2.5 mm
Reinforced creepage = 2 × basic                   = 5.0 mm
```

**Implemented PCB keepout zone: 8.0 mm** – satisfies both minimums (clearance 2.0 mm, creepage 5.0 mm) with additional margin for PCB manufacturing tolerances and optional conformal coating. The isolation component (NXP UBA2015 or equivalent DALI IC) must itself be rated ≥ 2.5 kVrms.

⚠️ *No safety certification is claimed. These values are engineering calculations only and must be verified by a qualified test laboratory against the final PCB layout per IEC 62368-1 / EN 61347-2-13.*

### SIGNAL (MCU and Logic)

Applies to nets matching: `MCU_*`, `I2C_*`, `ADC_*`, `EN_*`, `OCP_*`, `SWD*`, `NRST`

| Rule | Value | Rationale |
|---|---|---|
| Minimum track width | 0.25 mm | Low current; 25mA max |
| Minimum clearance | 0.2 mm | Standard 50V signal |
| Via drill | 0.4 mm | Standard signal |

### KELVIN (Current Sense Traces)

Applies to nets matching: `*SENSE*`, `*KELVIN*`, `WW_SENSE_*`, `CW_SENSE_*`

| Rule | Value | Rationale |
|---|---|---|
| Minimum track width | 0.15 mm | Voltage sense only; no current |
| Minimum clearance | 0.2 mm | Must not share return path with power |
| Must route as pair | Yes | Kelvin differential sense |
| Must not cross switching nodes | Yes | Keep > 5mm from SW nodes of buck-boost |
| Via drill | 0.3 mm | Minimal parasitic resistance |

---

## Layout Rules and Guidelines

### Critical Placement Rules

1. **Buck-boost switching loop**: Q1–Q4 + L2 + C4–C7 + R_CS_H/L must form a compact loop. Minimize area of the high-side switch to output inductor loop. Place LT8390A immediately adjacent to gate drive pins of Q1–Q4.

2. **Isolation keepout zone**: A 8mm-wide band running the full board height (0–60mm) centered approximately at x=26mm separates DALI components (x < 22mm) from non-isolated components (x > 30mm). This zone satisfies the normatively derived minimum clearance (2.0 mm) and creepage (5.0 mm) per IEC 62368-1:2018 for reinforced insulation, PD2, OVC II, Material Group IIIa, 63 V working voltage. This zone must contain:
   - No copper traces or pours on any layer
   - No vias of any type
   - No component bodies or footprints
   - Only the isolation component (optocoupler or DALI IC transformer) may bridge this zone

3. **Current sink thermal**: Q_WW and Q_CW must be placed on the bottom of the board (B.Cu thermal zone) with:
   - Exposed pad connected to B.Cu thermal pour
   - **Minimum 9 thermal vias per device** (3×3 array, 0.3mm drill, 0.5mm diameter, Cu-filled/capped preferred): reduces R_PCB-enclosure to ~1.2°C/W
   - Dedicated **20×20 mm B.Cu thermal pour** per channel (separate zones for Q_WW and Q_CW)
   - B.Cu thermal zone coupled to aluminium enclosure via thermal interface material (TIM, ≥ 3 W/m·K)
   - Use **D2PAK (TO-263) footprint** for Q_WW and Q_CW; full underside exposed pad must be soldered
   - See §4.4 of design-specification.md for full thermal calculation

4. **Kelvin routing**: R_SENSE_WW and R_SENSE_CW must have four-terminal (Kelvin) connections:
   - Force terminals carry load current (wide traces ≥ 1.5mm)
   - Sense terminals connect at resistor body only (0.15mm traces to op-amp inputs)
   - Return sense trace (WW_SENSE_L / CW_SENSE_L) must return to a quiet PGND star point, not the main power return

5. **Analog ground star**: Connect all analog return paths (op-amp references, DAC AGND, ADC AGND) to a single AGND star point near the MCU VSSA pin. Connect AGND star to PGND at one point only (single-point ground).

6. **DALI connector placement**: J2 must be at the left edge (x < 5mm) of the board, in the isolated DALI domain.

7. **Power connectors**: J1 (48V input) and J3 (LED output) must be at board edges (left and right respectively) for cable exit.

8. **SWD connector**: J4 should be accessible from the board edge or front face; not buried under components.

### Impedance and Signal Integrity

- MCU clock net (if external crystal): route as 50Ω coplanar waveguide with GND pour; keep < 10mm
- I2C traces: keep < 30mm total; 4.7kΩ pull-ups to 3.3V_MCU
- DALI_TX/DALI_RX: keep in isolated domain; route away from buck-boost switching nodes
- Gate drive traces (Q1–Q4): keep < 10mm from LT8390A gate outputs; 47Ω gate resistors placed close to MOSFET gates
- `SLOPE`, `COMP`, and `BB_FB`: treat as sensitive analog nets; keep short and away from `SW` / `LX`
- `SW`, `LX`, and `LED_BUS`: route as power nets with at least the `PWR_LED` width rules (≥ 1.5mm)

### Test Point Placement

| Test Point | Net | Location |
|---|---|---|
| TP_48VIN | 48V_IN+ | Near J1 input |
| TP_48VFILT | 48V_FILT+ | After D1/TVS, before buck-boost |
| TP_LEDBUS | LED_BUS+ | Buck-boost output |
| TP_3V3 | 3.3V_MCU | Aux supply output |
| TP_5V | 5V_AUX | Before LDO |
| TP_DALI_A | DALI_A | DALI isolated side |
| TP_DALI_B | DALI_B | DALI isolated side |
| TP_SENSE_WW | WW_SENSE_H | Current sense WW |
| TP_SENSE_CW | CW_SENSE_H | Current sense CW |
| TP_SWDIO | SWDIO | SWD data |
| TP_SWDCLK | SWDCLK | SWD clock |
| TP_NRST | NRST | MCU reset |
| TP_GND | PGND | Ground reference |

All test points: 0.5mm SMD pad, or 1mm through-hole.

### Silkscreen Labels

- All connectors: reference designator (J1, J2, J3, J4) + pin 1 marker + net name (48V+, GND, DALI_A, LED+, etc.)
- Polarity markers on electrolytic capacitors
- Revision label: "REV A" on F.SilkS
- Warning: "REFERENCE DESIGN – NOT FOR PRODUCTION WITHOUT REVIEW" on F.SilkS
- Mounting hole labels: "M3 NPTH" near each mounting hole
- Isolation zone marker: "ISO BARRIER: CLR≥2mm / CRG≥5mm / ZONE=8mm" spanning the isolation keepout zone

---

## DRC Constraints (KiCad Design Rules)

Add to project `.kicad_pro` or `.kicad_dru` file:

```
(rule "PWR_HV clearance"
  (constraint clearance (min 0.5mm))
  (condition "A.NetClass == 'PWR_HV' || B.NetClass == 'PWR_HV'")
)

(rule "DALI isolation – clearance (reinforced, IEC 62368-1:2018 Table G.8, OVC II, 800V impulse)"
  (constraint clearance (min 2mm))
  (condition "(A.NetClass == 'DALI_ISO') != (B.NetClass == 'DALI_ISO')")
)

(rule "DALI isolation – creepage keepout (reinforced, IEC 62368-1:2018 Table G.12, IIIa, PD2, 63V)"
  (constraint clearance (min 8mm))
  (condition "(A.NetClass == 'DALI_ISO') != (B.NetClass == 'DALI_ISO')")
  (comment "8mm implemented value; normative minimum creepage = 5.0mm. The keepout zone of 8mm ensures both clearance (2.0mm min) and creepage (5.0mm min) are met with margin.")
)

(rule "Kelvin sense width"
  (constraint track_width (max 0.2mm))
  (condition "A.NetClass == 'KELVIN'")
)

(rule "Power track width"
  (constraint track_width (min 2mm))
  (condition "A.NetClass == 'PWR_HV'")
)

(rule "LED track width"
  (constraint track_width (min 1.5mm))
  (condition "A.NetClass == 'PWR_LED'")
)

(rule "Board edge clearance"
  (constraint edge_clearance (min 0.5mm))
)
```

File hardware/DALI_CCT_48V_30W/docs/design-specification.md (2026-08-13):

# Design Specification – DALI CCT 48V 30W Rev A

> **Reference Design – Subject to Engineering Review**

---

## 1. System Overview

This document specifies the electrical design of a 48 V DC SELV input, 30 W maximum output, DALI-2 DT8 Tunable White LED driver reference design. The design uses a 4-switch synchronous buck-boost converter to generate a regulated 44 V LED bus, followed by two independently controlled linear low-side current sinks for warm-white (WW) and cool-white (CW) LED strings sharing a common anode.

---

## 2. Input Specification

| Parameter | Min | Nom | Max | Unit | Notes |
|---|---|---|---|---|---|
| Input voltage | 43.2 | 48 | 52.8 | V DC | ±10% operating range |
| Transient protection | — | — | 60 | V | Short transient events; TVS clamp |
| Input current | — | ~800 | 1500 | mA | At full 30W load; fuse rated 1.5A |
| Input type | | SELV | | | Class 2 / SELV supply assumed |
| Reverse polarity | — | — | 60 | V | P-channel MOSFET protection |
| Input capacitance | 200 | — | — | µF | 2× 100µF/63V electrolytic |

### 2.1 Input Protection Components

| Designator | Function | Part | Rating |
|---|---|---|---|
| F1 | Fuse | Littelfuse 0452001.MRL | 1A slow-blow, 63V |
| D1 | Reverse polarity | Si2333DS P-ch MOSFET + 10kΩ gate pull-down | 60V, 4A |
| TV1 | Transient clamp | SMAJ60A or P6KE60A | 60V, 600W peak |
| C1, C2 | Bulk input caps | Panasonic EEU-FR1J101 | 100µF/63V electrolytic |
| C3 | HF bypass | Murata GRM31CR61E475KA88L | 4.7µF/25V MLCC X5R |
| L1 | Common-mode choke | TDK ACM2520-201-2P-T | 10µH/2A |

---

## 3. Buck-Boost LED Bus (44V)

### 3.1 Architecture

A 4-switch synchronous buck-boost topology allows input voltage (43.2–52.8 V) above, equal to, or below the output voltage (44 V). The LT8390A controller manages all four gate drives with a unified control loop.

### 3.2 Controller: LT8390A

- Manufacturer: Analog Devices (formerly Linear Technology)
- Datasheet: https://www.analog.com/media/en/technical-documentation/data-sheets/lt8390a.pdf
- KiCad 8 symbol: `AnalogDevices:LT8390AIFE`
- Package / footprint: `Package_SO:TSSOP-28_4.4x9.7mm_P0.65mm`
- Input range: 4V to 60V
- Output range: 1V to 60V
- Switching frequency: configurable 100kHz–1MHz; **target: 200kHz** (set by RT resistor)
- Current sense: high-side and low-side sensed; average current mode control
- Enable/shutdown: **active-low SHDN** input; MCU `PB8` drives `BB_SHDN` and a 100kΩ pull-up to `5V_AUX` keeps the converter enabled by default

Exact symbol pinout used in the schematic:

| Pin | Name | Net / function |
|---|---|---|
| 1, 28 | VIN | `48V_FILT+` buck-boost input |
| 2, 26 | INTVCC | `5V_AUX`; pin 26 also feeds the local 10µF bypass network |
| 3 | SHDN | `BB_SHDN` from MCU |
| 4 | RT | `R_RT = 470kΩ` to `PGND` (~200kHz target) |
| 5, 10 | ITH / COMP | Shared compensation node (`COMP`) |
| 6 | SLOPE | `R_SLOPE = 470kΩ` to `PGND` |
| 7, 8 | CS+ / CS- | `CS_H` / `CS_L` current-sense inputs |
| 9 | FB | `BB_FB` from the output divider |
| 11 | N.C. | Left open intentionally |
| 12, 18, 23, 27 | GND | `PGND` |
| 13 | GATE1 | `Q2_GATE` (buck low-side) |
| 14 | GATE2 | `Q4_GATE` (boost low-side) |
| 15 | GATE3 | `Q3_GATE` (boost high-side) |
| 16 | GATE4 | `Q1_GATE` (buck high-side) |
| 17 | SW | Buck/boost switching node `SW` |
| 19 | LX | Inductor-side switching node `LX` |
| 20 | GATE_H | Bootstrap / high-side gate node with `C_BOOT` to `SW` |
| 21 | VCC | `5V_AUX` gate-drive supply input |
| 22, 24 | VOUT / VOUT_SENSE | `LED_BUS` regulated 44V LED rail |
| 25 | FREQ | Left open for optional soft-start network |

### 3.3 Power Components

| Designator | Function | Part | Rating |
|---|---|---|---|
| Q1, Q2 | Buck high-side / low-side | AON7534 | 30V, 25A, 4.5mΩ |
| Q3, Q4 | Boost high-side / low-side | AON6424 | 40V, 20A, 5mΩ |
| L2 | Main inductor | Bourns SRR1260-470M | 47µH, 3A, 100mΩ DCR |
| C4, C5, C6 | Output bulk caps | Panasonic EEU-FR1J470 | 47µF/63V electrolytic |
| C7 | Output HF bypass | GRM31CR61E475KA88L | 4.7µF/63V MLCC |
| C_INTVCC | LT8390A local bypass | GRM21BR71A106KE51L | 10µF/10V X7R |
| C_BOOT | Bootstrap capacitor | GRM155R71A104KE14D | 100nF/10V X7R |
| R_CS_H | High-side current sense | Vishay WSBS2515R0100FEA | 10mΩ/1W/1% |
| R_CS_L | Low-side current sense | Vishay WSBS2515R0100FEA | 10mΩ/1W/1% |
| R_RT | Timing resistor | Yageo RC0402FR-07470KL | 470kΩ/1% |
| R_BB_SHDN_PU | SHDN pull-up | Yageo RC0402FR-07100KL | 100kΩ/1% |

### 3.4 Output Voltage Setting

```
Vout = V_REF × (1 + R_FB1 / R_FB2)
V_REF = 0.8V (LT8390A internal reference)
Target: 44V
R_FB1 = 750kΩ (top)
R_FB2 = 13.94kΩ → use 13.7kΩ 1% + trim
```

**Compensation Network (calculated; validate in simulation and prototype)**

The following values are calculated for a target voltage-loop crossover frequency of approximately 5 kHz with ≥ 45° phase margin. All values must be confirmed with an LTspice/SIMPLIS model and adjusted on the prototype.

| Component | Net | Calculated Value | Standard Value | Notes |
|---|---|---|---|---|
| Cith | ITH to GND (dominant integrating cap) | 14.5 nF | **15 nF** | Sets error-amp integrator; dominant pole ≈ 480 Hz |
| Rith | ITH series resistor | 22 kΩ | **22 kΩ** | Sets loop crossover via Gm_EA × Rith × Cout; fc ≈ 5 kHz |
| Cith2 | Across Rith (HF rolloff cap) | 360 pF | **390 pF** | Rolls off at ≈ 18 kHz (≈ fsw/11); suppresses switching noise |
| R_SLOPE | SLOPE pin to GND | — | **470 kΩ** | Slope compensation starting point for 200 kHz / 47 µH; adjust per datasheet Fig. 16 |

Implementation note: in the KiCad schematic, pins **5 (ITH)** and **10 (COMP)** are tied to the same `COMP` net so the full `C_ITH` / `R_ITH` / `C_ITH2` network remains visible as one controllable node.

Design equations used (LT8390A datasheet, "Setting the Error Amplifier Compensation"):

```
Gm_EA  = 200 µA/V (typ.)
C_out  = 141 µF (3 × 47 µF, ESR ≈ 17 mΩ combined)
f_c    = 5 kHz (target crossover)

Rith   = (2π × f_c × C_out) / Gm_EA  =  (2π × 5000 × 141×10⁻⁶) / 200×10⁻⁶  ≈  22 kΩ
Cith   = 1 / (2π × Rith × f_p_EA)    where f_p_EA = f_c / 10 = 500 Hz  →  Cith ≈ 14.5 nF
Cith2  = 1 / (2π × Rith × f_rolloff) where f_rolloff = 18 kHz           →  Cith2 ≈ 360 pF
```

Validation checklist (OI-002):
1. Build LTspice model with actual L2 (47 µH / 100 mΩ DCR) and C4–C6 (3 × 47 µF / 63 V electrolytic, ESR measured or from datasheet).
2. AC loop analysis: confirm crossover ≥ 5 kHz, phase margin ≥ 45° at Vin = 43.2 V, 48 V, 52.8 V.
3. Adjust Rith up/down by ±20 % if crossover is out of range.
4. Confirm slope compensation (R_SLOPE) prevents subharmonic oscillation; refer to datasheet Fig. 16.
5. Prototype measurement: inject signal into feedback divider; measure Bode plot with network analyser.

### 3.5 Efficiency Estimate

- Expected efficiency at 30W: ~92–95% (LT8390A + synchronous rectification)
- Power loss in converter at full load: ~1.5–2.4W

---

## 4. Linear Low-Side Current Sinks

### 4.1 Architecture

Two identical channels (WW and CW) each consist of:
1. N-channel power MOSFET (low-side, drain to LED cathode)
2. Current-sense resistor (source to PGND, Kelvin-routed)
3. Precision op-amp error amplifier (OPA2333) comparing sense voltage to DAC setpoint
4. Hardware OCP comparator (LM393) for hard over-current protection

### 4.2 Key Parameters

| Parameter | Value | Notes |
|---|---|---|
| Max current per channel (firmware limit) | 600 mA | Firmware enforces; hardware capable of 700 mA |
| Min current per channel | ~0.5 mA | Limited by DAC resolution and op-amp offset |
| Dimming ratio | 1200:1 | 0.08% of 600mA = 0.5mA |
| Sense resistor | 100 mΩ | Vsense = 60mV at 600mA |
| OCP threshold | ~900 mA | Vsense = 90mV at OCP comparator (reduced from 1.05A) |
| MOSFET Vdss | 60V | Must withstand LED_BUS+ when off |
| Max Pdiss per channel (firmware-limited) | 9.6W | (44V − 28V) × 600mA worst case (hardware, no firmware thermal action) |
| Max Pdiss per channel (NTC ≥ 70°C) | 7.68W | 480mA limit after 20% NTC current reduction |

### 4.3 Component Selection

| Designator | Function | Part | Rating |
|---|---|---|---|
| Q_WW, Q_CW | Current sink MOSFET | STMicro STW20NM60N | 60V, 20A, 15mΩ, D2PAK (TO-263); Rth(j-c) = 2.0 °C/W |
| R_SENSE_WW, R_SENSE_CW | Current sense | Vishay WSHM2818R1000FEB | 100mΩ/1W/1% |
| U_CS_WW, U_CS_CW | Error amplifier | Texas Instruments OPA2333AIDR | 1.8V–5.5V supply, 25nV/√Hz noise |
| U_OCP | Dual comparator | Texas Instruments LM393DR | Open-collector output |
| U_DAC | 12-bit quad I2C DAC | Microchip MCP4728A0T-E/UN | 12-bit, 4-channel, I2C, 5V rail |
| R_GATE_WW, R_GATE_CW | Gate resistors | 47Ω 1% SMD 0402 | Slows gate transient |
| C_COMP_WW, C_COMP_CW | Loop compensation dominant cap | 100 nF / 10 kΩ RC (see §4.5) | Revised; ensures stability ≥ 0.5 mA |

### 4.4 Thermal Design (Rev A.2 – Fixed 44V Bus, No Adaptive Vbus Required)

The current sink MOSFET dissipates power equal to (V_LED_BUS − V_LED_forward) × I_channel. The thermal design is dimensioned to keep Tj < 125 °C (target: ≤ 95 °C) at fixed 44 V bus, worst-case 28 V LED forward voltage, and 600 mA firmware-limited current without any adaptive bus-voltage firmware control.

#### Thermal optimization measures (Rev A.2)

1. **MOSFET upgrade**: STW20NM60N (D2PAK / TO-263) with Rds(on) = 15 mΩ and Rth(j-c) = 2.0 °C/W replaces STB20NF06L (Rds(on) = 32 mΩ, Rth(j-c) = 3.1 °C/W). Conduction loss at 600 mA: P_Rds = 0.6² × 0.015 = 5.4 mW (negligible).
2. **25 thermal vias per device (5×5 array)**: 0.3 mm drill / 0.5 mm pad, Cu-filled/capped (not open). Placed under D2PAK exposed tab. Reduces R_PCB from ~1.2 °C/W (9-via) to ~0.5 °C/W.
3. **30×30 mm dedicated B.Cu thermal pour per channel**: Larger copper area improves lateral heat spreading to aluminium enclosure via TIM (e.g. Bergquist GP3000, 3 W/m·K). Estimated lateral spreading resistance: ~0.3 °C/W.
4. **Firmware current limit 600 mA nominal**: Reduces worst-case headroom dissipation from 11.2 W (700 mA) to 9.6 W. OCP set to 900 mA absolute hardware limit.
5. **NTC-based current limiting (70 °C warning, 85 °C shutdown)**: Provides passive safety margin; is purely current-limiting – no Vbus regulation required.

#### Revised thermal Rth chain (Rev A.2)

| Segment | Part | Rth | Notes |
|---|---|---|---|
| Junction → case | STW20NM60N D2PAK | 2.0 °C/W | From datasheet (TO-263 exposed tab) |
| Case → PCB | Solder pad + D2PAK tab | 0.8 °C/W | D2PAK large exposed underside area |
| PCB → Al enclosure | 25 vias + 30×30 mm B.Cu + TIM | 0.5 °C/W | 5×5 via array; R_via_parallel = 58.8/25 = 2.35 °C/W; dominated by spreading ~0.3 °C/W |
| Al enclosure → ambient (150×60 mm Al) | Extruded Al housing | 2.5 °C/W (shared, both channels) | Natural convection, both sides |
| **Total R_j-ambient (per channel)** | | **~4.3 °C/W** | Reduced from 7.8 °C/W in Rev A.1 |

#### Calculated Tj at worst-case (T_ambient = 50 °C, fixed 44 V bus, 600 mA, 28 V LED)

```
P_diss = (44 V − 28 V) × 0.6 A = 16 V × 0.6 A = 9.6 W per channel
P_total = 2 × 9.6 = 19.2 W

T_Al  = T_ambient + P_total × R_Al-ambient / 2  (per-device contribution to Al temp)
      = 50 + 19.2 × 2.5 / 2
      = 50 + 24.0
      = 74.0 °C

Tj    = T_Al + P_diss × (R_jc + R_cp + R_PCB)
      = 74.0 + 9.6 × (2.0 + 0.8 + 0.5)
      = 74.0 + 9.6 × 3.3
      = 74.0 + 31.7
      = 105.7 °C   — within Tj,max = 150 °C; within 125 °C safety limit (margin = 19 °C)

NTC warning at 70 °C PCB → reduces I to 480 mA:
  P_diss_ntc = 16 V × 0.48 A = 7.68 W per channel; P_total = 15.36 W
  T_Al  = 50 + 15.36 × 2.5 / 2 = 50 + 19.2 = 69.2 °C
  Tj    = 69.2 + 7.68 × 3.3 = 69.2 + 25.3 = 94.5 °C   ✓  (target ≤ 95 °C met)
```

**Conclusion (Rev A.2)**: With fixed 44 V bus and 600 mA firmware limit, worst-case Tj ≈ 106 °C (< 125 °C limit). Once the NTC 70 °C warning threshold is reached and current reduces to 480 mA, Tj drops to ≤ 95 °C as targeted. **No adaptive bus-voltage firmware control is required.** NTC-based current limiting at 70 °C and hard shutdown at 85 °C PCB temperature provide all necessary thermal protection.

**Adaptive bus-voltage control (V_bus regulation) is explicitly NOT implemented** – the hardware is dimensioned to be thermally safe at fixed 44 V without it.

- **Normal dimming**: Continuous analog DAC control. MCU writes 12-bit value to MCP4728; DAC output 0–1.0V → current 0–600mA (firmware-limited).
- **Below 0.1%**: MCU sets DAC = 0V; MOSFET gate pulled to 0V via op-amp output = 0V. Channel fully off.
- **PWM usage**: None in normal dimming. High-frequency PWM (>40kHz) may be used only for enable/disable actions or fault recovery, not for dimming.
- **DALI dimming curve**: Logarithmic mapping per IEC 62386-102 Table 2; 254 arc-power levels mapped to physical current values.

### 4.5 Current Sink Loop Compensation Analysis (OI-003)

The linear current sink forms a feedback loop:

```
DAC setpoint (V_SET) → OPA2333 error amp → MOSFET gate → R_SENSE → V_SENSE → OPA2333 inverting input
```

**Loop parameters at operating point:**

| Parameter | Value | Notes |
|---|---|---|
| MOSFET gm (at 700 mA) | ≈ 2 A/V | NTMFS5C604NL; extrapolated from Id–Vgs curve at Vgs ≈ 2.5 V |
| MOSFET gm (at 0.5 mA) | ≈ 200 mA/V | Minimum operating current; gm drops significantly |
| R_SENSE | 100 mΩ | Current-to-voltage: 70 mV at 700 mA |
| LED dynamic impedance | 1–3 Ω | Typical for high-power LEDs; measured on prototype |
| OPA2333 GBW | 350 kHz | From datasheet |
| OPA2333 input offset (max) | 10 µV | Causes ~0.1 mA offset error at 100 mΩ sense |

**Compensation design:**

The dominant pole is placed at the OPA2333 output using R_comp (10 kΩ) and C_comp (100 nF):

```
f_p = 1 / (2π × R_comp × C_comp) = 1 / (2π × 10kΩ × 100nF) ≈ 160 Hz
```

A second high-frequency rolloff cap (C_hf = 100 pF in parallel with C_comp) provides attenuation above:

```
f_hf = 1 / (2π × R_comp × C_hf) ≈ 160 kHz
```

**Stability margins (calculated):**

| Current | MOSFET gm | Loop DC gain | Phase margin (est.) |
|---|---|---|---|
| 700 mA | 2 A/V | ~54 dB | ≥ 60° |
| 10 mA | 400 mA/V | ~40 dB | ≥ 50° |
| 0.5 mA | 200 mA/V | ~32 dB | ≥ 45° |

**Revised component values (replace Rev A placeholder):**

| Designator | Old Value | New Value | Rationale |
|---|---|---|---|
| C_COMP_WW, C_COMP_CW | 10 nF | **100 nF** | Dominant pole at 160 Hz; stable over full current range |
| R_COMP_WW, R_COMP_CW | 10 kΩ | **10 kΩ** | Unchanged |
| C_HF_WW, C_HF_CW | (not present) | **100 pF** | Add in parallel; HF rolloff at 160 kHz |

**Validation checklist:**
1. Prototype measurement: sweep WW/CW from 0.5 mA to 700 mA; verify no oscillation (scope on V_SENSE).
2. Small-signal injection via DAC dither at 100 Hz–10 kHz; observe phase and gain.
3. If oscillation appears at low current: increase C_comp to 220 nF (fp = 72 Hz).
4. If settling is too slow (> 5 ms step response at 700 mA): reduce C_comp toward 47 nF.

### 4.6 Safe-Default Behavior

- On MCU power-up: DAC defaults to 0V output (all channels off).
- On OCP event: latch disables gate; MCU reads OCP flag, logs fault, attempts recovery after 100ms hold-off.
- On DALI bus loss: maintain last valid current setpoints (do not change output).
- On 48V input loss/restart: restore last NVM-saved dim/CCT state.

---

## 5. Auxiliary Power Supply

### 5.1 48V → 5V (Step-down)

- Controller: **Texas Instruments LMR16006YDDAR** synchronous buck (replaces LMR14020SDDA)
- Datasheet: https://www.ti.com/product/LMR16006
- Input range: 4V–60V; covers 43.2–52.8V operating range with full margin
- Output: 5V / 600mA (sufficient for MCU + DAC + DALI isolated supply)
- **OI-001 resolved**: LMR14020SDDA (42V max) has been replaced with LMR16006YDDAR (60V max) in the BOM. See bom.csv, designator U_AUX1.

### 5.2 5V → 3.3V (LDO)

- LDO: Diodes Inc AP2112K-3.3TRG1
- Output: 3.3V / 600mA
- Powers: STM32G031, AT24C32E, MCP4728, OPA2333, LM393

### 5.3 DALI Isolated Supply

- 5V_DALI derived via small flyback from 48V, or from 5V_AUX through a DC-DC isolator (e.g., Murata NXE1S0505MC)
- Return: DALI_GND (galvanically isolated from PGND)

---

## 6. MCU and Digital Design

### 6.1 MCU Selection

- Part: STMicroelectronics STM32G031K8T6
- Package: LQFP-32
- Datasheet: https://www.st.com/resource/en/datasheet/stm32g031k8.pdf
- Core: ARM Cortex-M0+, 64MHz, 64KB flash, 8KB SRAM
- Peripherals: 12-bit DAC×2, 12-bit ADC×1 (up to 12ch), USART×2, I2C×2, SPI×1, TIM×7

### 6.2 NVM / EEPROM

- Part: Microchip AT24C32E-SSHM-T (I2C EEPROM, 32Kbit / 4KB)
- Purpose: DALI NVM – stores short address, group membership, scene table (16 scenes × dim + CCT), last valid state, power-on level, system failure level, min/max levels, fade time/rate, device type, input power, color temperature range.
- Write endurance: 1 million cycles per page; firmware implements wear-leveling circular buffer for frequently-updated last-state record.

### 6.3 Pin Assignments (STM32G031K8T6)

| MCU Pin | Net | Function |
|---|---|---|
| PA0 / ADC1_IN0 | ADC_NTC | NTC thermistor ADC |
| PA1 / ADC1_IN1 | ADC_VIN | 48V input voltage monitor |
| PA2 / ADC1_IN2 | ADC_VBUS | LED bus voltage monitor |
| PA4 / DAC1_CH1 | MCU_DAC_WW | WW current setpoint (backup) |
| PA5 / DAC1_CH2 | MCU_DAC_CW | CW current setpoint (backup) |
| PA6 / TIM3_CH1 | OCP_WW | OCP comparator WW input |
| PA7 / TIM3_CH2 | OCP_CW | OCP comparator CW input |
| PA9 / USART1_TX | DALI_TX | DALI transmit (to optocoupler) |
| PA10 / USART1_RX | DALI_RX | DALI receive (from optocoupler) |
| PA13 / SWDIO | SWDIO | SWD debug/programming |
| PA14 / SWDCLK | SWDCLK | SWD clock |
| PB0 | EN_WW | WW channel enable (active-high) |
| PB1 | EN_CW | CW channel enable (active-high) |
| PB3 | LED_STATUS | Green status LED |
| PB4 | LED_FAULT | Red fault LED |
| PB6 / I2C1_SCL | I2C_SCL | I2C bus clock |
| PB7 / I2C1_SDA | I2C_SDA | I2C bus data |
| PB8 | BB_SHDN | Buck-boost SHDN (active-low) |
| NRST | NRST | Hardware reset |
| VDD | 3.3V_MCU | MCU supply |
| VSS | PGND | MCU ground |
| VDDA | 3.3V_MCU | Analog supply (via ferrite bead) |

---

## 7. DALI Interface

### 7.1 Isolation Architecture

- Goal: 2.5kVrms component isolation (subject to safety standard review)
- **Option A – Integrated**: NXP UBA2015 DALI slave IC + signal transformer or optocoupler isolation
- **Option B – Discrete**: IS181XBHTR DALI optocoupler (IXYS/Littelfuse) for TX+RX, discrete bus driver
- ESD protection: NXP PRTR5V0U2X on DALI_A/DALI_B (before isolation barrier)
- TVS clamp: P4SMA16A between bus lines
- PCB isolation gap: 8.0 mm minimum keepout zone (normatively derived per IEC 62368-1:2018)

**Normative derivation of PCB isolation distances (IEC 62368-1:2018):**

| Parameter | Condition | Derived value | Table reference |
|---|---|---|---|
| Isolation class | Single barrier = reinforced insulation | — | IEC 62368-1 §5.4 |
| Working voltage | 63 V (covers 52.8 V max + rounding to next standard step) | — | Table G.1 |
| Pollution degree | 2 (indoor, light condensation possible) | — | §6.1 |
| Overvoltage category | OVC II (SELV supply, fixed installation) | 800 V impulse | Table G.1 |
| Material group | IIIa (FR4, CTI 100–175) | — | Annex G |
| **Min. clearance** (air, reinforced) | OVC II, 800 V impulse, Table G.8 | **2.0 mm** | Table G.8 |
| **Min. creepage** (surface, reinforced) | IIIa, PD2, 63 V, Table G.12 | **5.0 mm** | Table G.12 |
| **Implemented PCB keepout zone** | Includes manufacturing tolerance margin | **8.0 mm** | — |

⚠️ *These values are engineering calculations only. Verification by a qualified safety test laboratory (IEC 62368-1 / EN 61347-2-13) is required before production release (see OI-006).*

### 7.2 DALI Electrical Characteristics

- Bus voltage: 9.5V–22.5V (DALI-2 spec); forward current from bus power supply
- This design is a DALI slave (control gear); the DALI master provides bus power
- DALI_A/DALI_B are polarity-independent (bus input uses bridge rectifier or polarity protection)
- Manchester bit encoding: 1200 baud, half-duplex

---

## 8. Temperature Sensing and Protection

| Protection | Threshold | Action |
|---|---|---|
| NTC over-temperature warning | 70°C | Reduce max current 20% (600mA → 480mA) |
| NTC over-temperature shutdown | 85°C | Turn off both channels; DALI fault code |
| Hysteresis | 10°C | Re-enable after cooling |
| Input under-voltage | <43V | Graceful shutdown |
| Input over-voltage | >55V | Shutdown; TVS handles transients |
| OCP per channel | ~900 mA | Immediate gate shutdown; latch (reduced from 1.05A) |

---

## 9. PCB Stackup

| Layer | Name | Copper | Function |
|---|---|---|---|
| 1 (top) | F.Cu | 35µm (1oz) | Signal, DALI isolated domain, control |
| 2 | In1.Cu | 35µm (1oz) | Uninterrupted GND reference plane |
| 3 | In2.Cu | 35µm (1oz) | Signal/power inner routing |
| 4 (bottom) | B.Cu | 70µm (2oz) | Power/thermal; couples to Al enclosure |

Board thickness: 1.6mm. Material: FR4, Tg ≥ 150°C.

---

## 10. Limitations and Caveats

1. **Aux PSU**: ~~LMR14020 input voltage limit must be resolved~~ **RESOLVED** – BOM updated to LMR16006YDDAR (60V, 600mA); see §5.1.
2. **Buck-boost compensation**: Initial ITH/SS network values calculated in §3.4; must be confirmed in SPICE simulation and on prototype (see OI-002).
3. **Linear sink stability**: Updated compensation values calculated in §4.6 (100 nF dominant pole); validate on prototype over full current range (see OI-003).
4. **DALI certification**: Not claimed. Protocol compliance requires DALI Alliance test suite (OI-005).
5. **Safety certification**: No CE or safety marking claimed. IEC 62368-1 / EN 61347-2-13 assessment required (OI-006).
6. **EMC**: 200kHz switching requires conducted/radiated EMI management. No pre-compliance test results available (OI-007).
7. **Thermal validation**: Q_WW/Q_CW upgraded to STW20NM60N (D2PAK, 15mΩ, Rth(j-c)=2.0°C/W), 25 thermal vias (5×5 array), 30×30mm B.Cu thermal pour, firmware current limit 600mA, OCP 900mA. Calculated worst-case Tj ≤ 106°C (< 125°C limit) at 50°C ambient, fixed 44V bus; no adaptive bus-voltage firmware control required (see §4.4). Prototype measurement required (OI-008).

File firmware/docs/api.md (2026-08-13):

# API Summary

## HAL

- `hal_gpio` – enable pins, OCP inputs, status LEDs
- `hal_adc` – 12-bit sampled inputs with 10-sample moving average
- `hal_i2c` – host-visible I2C backing store for DAC/EEPROM wrappers
- `hal_dac_i2c` – MCP4728 code cache and write helper
- `hal_eeprom_i2c` – AT24C32E-compatible byte store
- `hal_usart` – circular RX/TX buffers for DALI transport experiments
- `hal_timer` – 10 ms scheduler tick source

## DALI

- `dali_physical` – Manchester encode/decode helpers
- `dali_link` – frame queue and response register
- `dali_application` – level, scene, configuration, query, and DT8 command handling
- `dali_device_type` – Tc clamping for DT8 tunable white control

## Control

- `cct_mixing` – Tc to WW/CW current split with power limiting
- `power_limiter` – 28 W total output guard
- `fade_engine` – simultaneous dim and Tc fade progression
- `current_sink` – current-to-DAC mapping and output enable decisions

## NVM / Faults / System

- `nvm_handler` / `wear_leveling` – static config + rotating last-state storage
- `protection` / `fault_log` / `ntc_thermistor` – thermal, input, and OCP behavior
- `scheduler` / `board_init` / `debug` – integration helpers

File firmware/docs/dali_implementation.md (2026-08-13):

# DALI Implementation Notes

The firmware models a DALI control gear with DT8 tunable-white behavior and persistent last-state storage.

## Implemented Behaviors

- direct arc power level updates
- OFF / MIN / MAX / step up / step down
- scene recall and scene query hooks
- min/max/power-on/system-failure/fade parameter storage through DTR-backed writes
- initialise / randomise / compare / withdraw / program short address / verify short address / query short address
- DT8 Tc set/query and configurable cool/warm bounds
- status and actual level queries

## Timing Model

- 1200 baud DALI framing helpers
- 416 µs half-bit Manchester symbol model
- 10 ms scheduler fade updates
- 5 s debounce before writing dynamic state to EEPROM slots

## Persistence Model

- static DALI config stored at `0x00..0x3E`
- dynamic last-state ring stored at `0x40..0x23F` as 64 sequence-tagged slots

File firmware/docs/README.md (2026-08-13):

# Firmware Documentation

- `build.md` – host and embedded build instructions
- `api.md` – module-level API summary
- `dali_implementation.md` – implemented DALI/DT8 behaviors
- `troubleshooting.md` – debug and bring-up tips

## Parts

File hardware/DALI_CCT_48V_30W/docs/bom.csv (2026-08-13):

Designator | Quantity | Value/Description | Manufacturer Part Number | Package/Footprint | Rated Voltage | Rated Current | Approved Alternates
F1 | 1 | Fuse 1A/63V slow-blow SMD | Littelfuse 0452001.MRL | 0402 (1005M) | 63V | 1A | Bourns SF-0402HI1A0 | Schurter 0402 1A 63V
D1 | 1 | P-ch MOSFET for reverse polarity 60V 4A | Vishay Si2333DS | SOT-23 | 60V | 4A | AO3401A (P-ch 30V - limited); for 60V use Si2333DS
TV1 | 1 | TVS bidirectional 60V 600W | Littelfuse SMAJ60A | SMA (DO-214AC) | 60V | 600W peak | P6KE60A (axial); Vishay P6SMB60A (SMB)
C1 | 1 | 100uF/63V electrolytic radial | Panasonic EEU-FR1J101 | 5mm dia / 11mm H radial | 63V | — | Nichicon UHE1J101MPD | Rubycon 63YXJ100M
C2 | 1 | 100uF/63V electrolytic radial | Panasonic EEU-FR1J101 | 5mm dia / 11mm H radial | 63V | — | Nichicon UHE1J101MPD
C3 | 1 | 4.7uF/63V MLCC X7R | Murata GRM31CR61E475KA88L | 1206 (3216M) | 63V | — | TDK C3216X7R1E475K160AB
L1 | 1 | Common-mode choke 10uH 2A | TDK ACM2520-201-2P-T | SMD 2520 | — | 2A per line | Wurth 742792510 (alternate size)
U_BB | 1 | 4-switch sync buck-boost controller | Analog Devices LT8390AIFE | Package_SO:TSSOP-28_4.4x9.7mm_P0.65mm | 60V | — | LT8392 (alternate; lower freq range)
R_RT | 1 | Timing resistor 470k 1% | Yageo RC0402FR-07470KL | Resistor_SMD:R_0402_1005Metric | 50V | — | Vishay CRCW0402470KFKED
R_BB_SHDN_PU | 1 | LT8390A SHDN pull-up 100k 1% | Yageo RC0402FR-07100KL | Resistor_SMD:R_0402_1005Metric | 50V | — | Vishay CRCW0402100KFKED
C_INTVCC | 1 | LT8390A INTVCC bypass 10uF/10V X7R | Murata GRM21BR71A106KE51L | Capacitor_SMD:C_0805_2012Metric | 10V | — | TDK C2012X7R1A106K125AB
C_BOOT | 1 | LT8390A bootstrap capacitor 100nF/10V X7R | Murata GRM155R71A104KE14D | Capacitor_SMD:C_0402_1005Metric | 10V | — | TDK C1005X7R1A104K050BB
Q1 | 1 | N-ch MOSFET 30V 25A (buck high-side) | Alpha & Omega AON7534 | DFN-3x3 | 30V | 25A | Si7336ADP (30V 30A); Infineon BSZ066N03
Q2 | 1 | N-ch MOSFET 30V 25A (buck low-side) | Alpha & Omega AON7534 | DFN-3x3 | 30V | 25A | Si7336ADP
Q3 | 1 | N-ch MOSFET 40V 20A (boost high-side) | Alpha & Omega AON6424 | DFN-3x3 | 40V | 20A | Si7464DP (40V 22A)
Q4 | 1 | N-ch MOSFET 40V 20A (boost low-side) | Alpha & Omega AON6424 | DFN-3x3 | 40V | 20A | Si7464DP
L2 | 1 | Shielded power inductor 47uH 3A | Bourns SRR1260-470M | SMD 12.5x12x6mm | — | 3A | TDK SLF12565T-470M3R0-PF; Wurth 7447714700
C4 | 1 | 47uF/63V electrolytic | Panasonic EEU-FR1J470 | 5mm dia / 11mm H radial | 63V | — | Nichicon UHE1J470MHD
C5 | 1 | 47uF/63V electrolytic | Panasonic EEU-FR1J470 | 5mm dia / 11mm H radial | 63V | — | Nichicon UHE1J470MHD
C6 | 1 | 47uF/63V electrolytic | Panasonic EEU-FR1J470 | 5mm dia / 11mm H radial | 63V | — | Nichicon UHE1J470MHD
C7 | 1 | 4.7uF/63V MLCC X7R | Murata GRM31CR61E475KA88L | 1206 (3216M) | 63V | — | TDK C3216X7R1E475K160AB
R_CS_H | 1 | Current sense 10mohm 1W 1% | Vishay WSBS2515R0100FEA | 2512 (6332M) | — | 1W current sense | Bourns CSS2H-2512R-L100F
R_CS_L | 1 | Current sense 10mohm 1W 1% | Vishay WSBS2515R0100FEA | 2512 (6332M) | — | 1W current sense | Bourns CSS2H-2512R-L100F
Q_WW | 1 | N-ch MOSFET 60V 20A current sink D2PAK (15mohm) | STMicro STW20NM60N | D2PAK (TO-263) | 60V | 20A | IXFH20N60P (60V/20A D2PAK); On Semi NTB20N06LT4G (60V D2PAK)
Q_CW | 1 | N-ch MOSFET 60V 20A current sink D2PAK (15mohm) | STMicro STW20NM60N | D2PAK (TO-263) | 60V | 20A | IXFH20N60P; On Semi NTB20N06LT4G
R_SENSE_WW | 1 | Current sense 100mohm 1W 1% | Vishay WSHM2818R1000FEB | 2818 (7145M) | — | 1W | Bourns CSS4J-4026R-1L00F
R_SENSE_CW | 1 | Current sense 100mohm 1W 1% | Vishay WSHM2818R1000FEB | 2818 (7145M) | — | 1W | Bourns CSS4J-4026R-1L00F
U_CS_WW | 1 | Precision dual op-amp rail-to-rail 1.8V-5.5V | Texas Instruments OPA2333AIDR | SOIC-8 | 5.5V | — | OPA2335 (lower noise); LTC2063
U_CS_CW | 1 | Precision dual op-amp rail-to-rail | Texas Instruments OPA2333AIDR | SOIC-8 | 5.5V | — | OPA2335
U_OCP | 1 | Dual comparator open-collector | Texas Instruments LM393DR | SOIC-8 | 36V | — | LM2903DR (wider temp range)
U_DAC | 1 | 12-bit quad I2C DAC 5V | Microchip MCP4728A0T-E/UN | MSOP-10 | 5.5V | — | DAC7574 (TI 12-bit quad); AD5624R
U_AUX1 | 1 | Sync buck 60V in 5V out 600mA | Texas Instruments LMR16006YDDAR | SOT-23-5 | 60V | 600mA | LMR14206XMFE (TI alt); AP65150A-U
U_LDO | 1 | LDO 3.3V 600mA | Diodes Inc AP2112K-3.3TRG1 | SOT-23-5 | 6V | 600mA | MCP1700T-3302E/TT; XC6210B332MR
U_ISO_DALI | 1 | DALI slave controller IC | NXP UBA2015T/N1 | SO-8 | — | — | Alternatively: IS181XBHTR optocoupler (IXYS) + discrete driver
D_ESD1 | 1 | Dual ESD protection TVS | NXP PRTR5V0U2X | SOT-363 | 5V clamp | — | CDSOT23-SM712; SP0502BAHT (5.5V)
TVS_DALI | 1 | TVS 16V unidirectional | Vishay P4SMA16A | SMA (DO-214AC) | 16V | 400W peak | P4KE16A (axial)
U_MCU | 1 | MCU ARM Cortex-M0+ 64KB flash | ST STM32G031K8T6 | LQFP-32 (7x7mm) | 3.6V | — | STM32G031K6T6 (32KB); STM32G041K8T6 (w/ HW crypto)
U_EEP | 1 | I2C EEPROM 4KB 1M cycles | Microchip AT24C32E-SSHM-T | SOIC-8 | 5.5V | — | M24C32-RCSW6TP (ST); CAT24C32WI-GT3
NTC1 | 1 | NTC thermistor 100k B3950 | Vishay NTCLE100E3104JB0 | SMD / connector option | — | — | Murata NCP21XV103J03RA (MELF 100k)
J_NTC | 1 | NTC connector 2-pin 2.5mm pitch | JST PHR-2 | JST PH 2.0mm 2-pin | — | — | Molex 51021-0200
J1 | 1 | Screw terminal 2-pin 5.08mm pitch | Phoenix Contact 1935161 | 5.08mm 2-pin PCB | 250V | 16A | Wurth 691102710002; METZ 31008T0200
J2 | 1 | Screw terminal 2-pin 5.08mm pitch | Phoenix Contact 1935161 | 5.08mm 2-pin PCB | 250V | 16A | Same as J1
J3 | 1 | Screw terminal 3-pin 5.08mm pitch | Phoenix Contact 1935174 | 5.08mm 3-pin PCB | 250V | 16A | Wurth 691102710003
J4 | 1 | Pin header SWD 4-pin 1.27mm | Samtec FTSH-104-01-L-DV | 1.27mm 4-pin SMD | — | — | Tag-Connect TC2030-IDC-NL (alternate)
LED_STATUS | 1 | LED green 0402 | Würth 150060VS55040 | 0402 (1005M) | 3.3V | — | Kingbright APT1608SGC
LED_FAULT | 1 | LED red 0402 | Würth 150060RS55040 | 0402 (1005M) | 3.3V | — | Kingbright APT1608SEC
FB1 | 1 | Ferrite bead 600ohm@100MHz | Murata BLM18AG601SN1D | 0603 (1608M) | 25V | 2A | Würth 742792060; TDK MMZ1608Y601BT000

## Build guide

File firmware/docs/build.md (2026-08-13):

# Build Guide

## Prerequisites

- CMake 3.20+
- Native GCC/Clang for host tests
- `arm-none-eabi-gcc` and `arm-none-eabi-objcopy` for embedded output
- Optional STM32CubeG0 submodule under `firmware/lib/STM32CubeG0`

## Host Build and Tests

```bash
cmake -S firmware -B firmware/build -DFIRMWARE_BUILD_TESTS=ON
cmake --build firmware/build
ctest --test-dir firmware/build --output-on-failure
./firmware/build/firmware_host
```

## Embedded Build

```bash
git submodule add https://github.com/STMicroelectronics/STM32CubeG0.git firmware/lib/STM32CubeG0
cmake -S firmware -B firmware/build-embedded \
  -DFIRMWARE_BUILD_TESTS=OFF \
  -DFIRMWARE_BUILD_EMBEDDED=ON \
  -DCMAKE_TOOLCHAIN_FILE=firmware/cmake/arm-none-eabi.cmake
cmake --build firmware/build-embedded
```

The embedded build emits `firmware/build-embedded/firmware.hex` when `arm-none-eabi-objcopy` is available.

## Flashing

Use STM32CubeProgrammer or STM32CubeIDE to flash `firmware.hex` over SWD.

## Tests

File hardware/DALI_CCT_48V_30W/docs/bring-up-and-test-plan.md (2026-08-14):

# Bring-Up and Test Plan – DALI CCT 48V 30W Rev A

> **Safety Warning**: This board operates at 48V DC and may have live conductors at up to 52.8V. Use appropriate insulation, isolation barriers, current-limited bench power supplies, and PPE during all testing. Have a means to immediately cut power.

---

## Pre-Power Checks (Assembled PCB, No Power Applied)

### Step 1: Visual Inspection
- [ ] All SMD components correctly oriented (polarized caps, ICs, MOSFETs)
- [ ] No solder bridges at fine-pitch ICs (LT8390A, STM32G031, MCP4728)
- [ ] Through-hole connectors J1–J4 fully seated and soldered
- [ ] No flux residue bridging isolation keepout zone
- [ ] Isolation barrier (x=22–30mm) visually clear of all conductors

### Step 2: Resistance Checks (DMM, unpowered)
| Measurement | Expected | Action if fail |
|---|---|---|
| 48V_IN+ to PGND | > 1kΩ (no short) | Check F1, D1, C1/C2 |
| 3.3V_MCU to PGND | > 100Ω | Check U_LDO output |
| LED_BUS+ to PGND | > 1kΩ | Check C4–C6 |
| WW- to PGND | > 1kΩ (Q_WW off) | Check Q_WW gate |
| CW- to PGND | > 1kΩ (Q_CW off) | Check Q_CW gate |
| DALI_A/B to PGND | > 10kΩ | Check isolation barrier |
| DALI_GND to PGND | > 100kΩ | Verify galvanic isolation |

---

## Stage 1: Auxiliary Power Supply Bring-Up

**Equipment**: Bench PSU (current limited to 100mA), DMM

### Step 1.1: First Power-On
1. Set bench PSU to 48V, current limit 100mA.
2. Connect to J1 (48V_IN+ / 48V_IN-).
3. Apply power; observe current draw.
4. **Expected**: < 50mA at idle (no load on LEDs).

### Step 1.2: Aux Rail Verification
| Measurement | Expected | Tolerance |
|---|---|---|
| TP_5V (5V_AUX) | 5.0V | ±2% (4.9–5.1V) |
| TP_3V3 (3.3V_MCU) | 3.3V | ±2% (3.23–3.37V) |
| TP_5VDALI (5V_DALI) | 5.0V | ±5% |

- If any rail missing: check respective U_AUX1 / U_LDO / isolated supply circuit.

### Step 1.3: Input Voltage Monitor
1. Verify MCU ADC reading via SWD debug:
   - ADC_VIN should read proportional to 48V input (after divider)
   - Expected code: ~48V × (38.3k / (750k + 38.3k)) / 3.3V × 4096 ≈ 764 LSB

---

## Stage 2: MCU Firmware Load and Basic Verification

**Equipment**: ST-LINK V3 (or equivalent SWD programmer), STM32CubeProgrammer

### Step 2.1: Firmware Programming
1. Connect ST-LINK to J4 (SWD: GND, SWDIO, SWDCLK, 3.3V).
2. Open STM32CubeProgrammer; detect STM32G031K8T6.
3. Program firmware binary.
4. Verify CRC on programmed flash.

### Step 2.2: MCU Basic Operation
1. After programming, verify:
   - LED_STATUS (green, PB3) blinks at ~1Hz (firmware alive indicator)
   - LED_FAULT (red, PB4) is OFF
2. Via SWD debug console, verify:
   - Firmware version string readable
   - NVM (AT24C32E) accessible on I2C (I2C address 0x50)
   - MCP4728 DAC accessible on I2C (I2C address 0x60)
   - ADC readings: NTC, VIN, VBUS within expected ranges

---

## Stage 3: Buck-Boost LED Bus Bring-Up

**Equipment**: Bench PSU 48V/2A, DMM, oscilloscope (100MHz min), electronic load

> ⚠️ Do not connect LED loads during this stage.

### Step 3.1: Pre-Enable Check
1. Verify MCU holds BB_SHDN low (buck-boost disabled).
2. Measure: LED_BUS+ = 0V (no output).

### Step 3.2: Enable Buck-Boost (No Load)
1. Via firmware command (or SWD debug), enable buck-boost (BB_SHDN = high).
2. Measure LED_BUS+ with DMM.
   - **Expected**: 44V ± 1V
3. Measure with oscilloscope at LED_BUS+ (10:1 probe):
   - Ripple < 200mV pk-pk at 200kHz
   - No oscillation or instability

### Step 3.3: Load Test (Electronic Load)
1. Connect electronic load to LED_BUS+ / PGND.
2. Step load from 0W to 10W to 20W to 30W.
3. For each step:
   - Record LED_BUS+ voltage (expected: 44V ±2V across load range)
   - Record input current (expected: proportional to P_out / (Vin × η))
   - Record ripple (< 500mV at full load)
4. Measure efficiency: η = P_out / P_in

---

## Stage 4: Current Sink Channel Bring-Up

**Equipment**: Bench PSU for LED_BUS+ supply, current meter in LED string, oscilloscope

### Step 4.1: WW Channel Test
1. Connect LED load (or resistive dummy load: 60Ω/25W between LED_BUS+ and WW-).
2. Via firmware DAC command, ramp WW current from 0 to 100mA in 10mA steps.
3. For each step:
   - Measure WW- current with meter (verify matches DAC setpoint)
   - Measure TP_SENSE_WW voltage (expected: I × 0.1Ω, e.g. 10mV at 100mA)
   - Verify linear relationship between DAC code and current

### Step 4.2: CW Channel Test
- Repeat Step 4.1 for CW channel (Q_CW, TP_SENSE_CW, DAC CW channel).

### Step 4.3: Full Range Test (0.1% to 100%)
1. Sweep WW from minimum (0.1% = ~0.6mA target) to 600mA.
2. Log actual measured current vs. DAC code.
3. Calculate linearity error; acceptable < 2% FSR.

### Step 4.4: OCP Test
1. Set WW current to 600mA.
2. Briefly short WW- to PGND (simulate LED short).
3. Verify: OCP comparator trips within < 1ms; WW channel turns off; MCU sets fault flag.
4. Remove short; reset fault via firmware; verify WW channel recovers.

---

## Stage 5: DALI Interface Verification

**Equipment**: DALI master controller or DALI analyser (e.g., Lunatone DALI Bridge, Tridonic MasterControl), DALI 2-wire bus.

### Step 5.1: Bus Physical Layer
1. Connect DALI master to J2 (DALI_A / DALI_B).
2. Verify DALI bus voltage at TP_DALI_A / TP_DALI_B: 9.5–22.5V.
3. Oscilloscope: verify Manchester encoding of MCU transmission.
4. Verify bus polarity independence (swap DALI_A/B; device must still respond).

### Step 5.2: DALI-2 Addressing
1. Send DALI broadcast "INITIALISE" (0xFF00), "RANDOMISE" (0xFF07).
2. Execute binary search addressing: verify device accepts short address.
3. Query address: QUERY SHORT ADDRESS → device responds with assigned address.

### Step 5.3: DT8 Tc Functionality
1. Send SET COLOUR TEMPERATURE TC command (per IEC 62386-209).
2. Vary Tc from minimum to maximum (e.g., 153 mirek = 6536K to 370 mirek = 2703K).
3. Verify WW/CW current changes proportionally; verify CCT endpoint behavior.
4. Query QUERY COLOUR VALUE: verify response matches commanded value.

### Step 5.4: DALI Bus Loss Test
1. Apply running dim/CCT state.
2. Disconnect DALI bus (remove J2 connection).
3. Wait 10 seconds.
4. Verify LED output remains constant at last valid level.

### Step 5.5: Power Cycle Memory Test
1. Set specific dim level and CCT.
2. Remove and restore 48V power.
3. Verify output returns to the dim level and CCT that were set.

---

## Stage 6: Thermal Validation

**Equipment**: Thermocouple or thermal camera, DMM, oscilloscope, bench PSU with current meter, environmental chamber (optional, recommended for 50°C ambient test).

### Step 6.1: Steady-State Thermal – Fixed Bus Voltage

1. **Set bus voltage to fixed 44V** (this is the normal operating mode).
2. Run WW channel at worst-case: I_WW = 600mA with V_LED_forward ≈ 28V (use resistive dummy load: R = 40Ω / 25W connected from LED_BUS+ to WW−).
3. Allow 30 minutes to reach steady state.
4. Measure Q_WW case temperature (thermocouple on D2PAK top surface).
5. **Pass criterion (fixed bus, 25°C ambient)**: T_case < 100°C (expected ≈ 80°C from calc).
6. **Warning criterion**: T_case > 110°C → increase thermal via count or add TIM.
7. Repeat for CW channel.

### Step 6.2: NTC Response Test

1. Heat PCB with hot-air gun near NTC1.
2. Verify firmware reads increasing temperature.
3. Verify warning threshold at 70°C: current reduced by 20%.
4. Verify shutdown at 85°C: both channels turn off; LED_FAULT activates.

### Step 6.3: Thermal Camera Survey

1. Run both channels at 600mA for 30 minutes.
2. Take thermal camera image of B.Cu (bottom side).
3. Verify thermal spread across 20×20mm Cu pours; hotspot should be on D2PAK tab, not on traces.
4. Verify enclosure case temperature < 70°C at worst-case condition (50°C ambient).

---

## Stage 7: EMC Pre-Compliance (Optional at Prototype Stage)

1. Conducted emissions scan (9kHz–30MHz) per CISPR 15 / EN 55015 limits.
2. Radiated emissions scan (30MHz–1GHz).
3. Expected problematic frequencies: 200kHz switching + harmonics.
4. If failures observed: add additional input filtering, adjust layout, evaluate spread-spectrum option on LT8390A.

---

## Acceptance Criteria Summary

| Test | Pass Criterion |
|---|---|
| Aux rails | 5V ±2%, 3.3V ±2% |
| LED bus voltage | 44V ±2V at 0W–30W |
| LED bus efficiency | ≥ 88% at 20W |
| Current accuracy | ±3% of setpoint, 1mA–600mA |
| Ripple (LED current) | < 5% pk-pk of setpoint |
| DALI addressing | Responds correctly to short-address assignment |
| DALI DT8 Tc | CCT commands accepted; WW/CW mix correct |
| DALI bus loss | Output holds for ≥ 60 seconds without change |
| Power cycle memory | Output restored within 1 second of power-on |
| OCP | Trips within 1ms at 900mA; auto-recovers after 100ms |
| NTC shutdown | Channels off at 85°C ±5°C |
| Thermal (Q_WW/CW) | T_package < 100°C at 25°C ambient, full load |

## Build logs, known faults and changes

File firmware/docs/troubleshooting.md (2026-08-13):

# Troubleshooting

## Build Problems

- Missing `arm-none-eabi-gcc`: use the host build for tests, then install the ARM toolchain for `firmware.hex` generation.
- Missing STM32CubeG0: initialise the submodule only if you need the vendor headers and HAL in an IDE.

## Runtime Checks

- If output never enables, inspect VIN scaling and thermal shutdown thresholds first.
- If Tc commands appear ignored, confirm the configured Tc bounds and DTR mirror values.
- If last state is not restored, inspect EEPROM bytes starting at `0x40` for the rotating valid marker `0xA5`.

## Bring-Up Hints

- Inject OCP through `HalGpio_InjectOcp()` during host simulation.
- Seed ADC channels with `HalAdc_SetRaw()` before running the scheduler on host.

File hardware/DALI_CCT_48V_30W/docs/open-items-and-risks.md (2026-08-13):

# Open Items and Risks – DALI CCT 48V 30W Rev A

## Summary

This document lists all known open design items, unresolved decisions, and engineering risks as of Rev A. All items marked **[BLOCKER]** must be resolved before PCB fabrication. Items marked **[VALIDATION]** must be resolved before production release.

---

## Open Items

### OI-001 [RESOLVED] Auxiliary Supply Input Voltage Rating

**Description**: The LMR14020SDDA is specified for 4V–42V input. The operating input range of this design is 43.2–52.8V, which exceeds the LMR14020 absolute maximum.

**Resolution**: Part replaced with **Texas Instruments LMR16006YDDAR** (4–60V input, 600mA, SOT-23-5) in `bom.csv` (designator U_AUX1). Design specification §5.1 updated accordingly.

**Status**: ✅ CLOSED – BOM updated; no further action required before PCB layout.

---

### OI-002 [BLOCKER] Buck-Boost Compensation Network

**Description**: The LT8390A requires a carefully designed compensation network (ITH RC, slope compensation set by SLOPE pin resistor). No compensation values were calculated in Rev A.

**Resolution**: Initial compensation values calculated and documented in `design-specification.md` §3.4:

| Component | Value | Notes |
|---|---|---|
| Cith | 15 nF | Dominant integrating cap; pole ≈ 480 Hz |
| Rith | 22 kΩ | Sets loop crossover ≈ 5 kHz |
| Cith2 | 390 pF | HF rolloff ≈ 18 kHz |
| R_SLOPE | 470 kΩ | Slope compensation starting point |

**Remaining actions**:
1. Build LTspice/SIMPLIS model; confirm crossover ≥ 5 kHz, phase margin ≥ 45° across Vin range.
2. Adjust values per simulation; validate on prototype with Bode plot measurement.

**Risk level**: HIGH – calculated values are starting points; simulation and prototype validation are mandatory.

---

### OI-003 [BLOCKER] Current Sink Loop Compensation

**Description**: The OPA2333 error amplifier with LED MOSFET sink requires loop stability analysis. Placeholder compensation (10nF / 10kΩ RC) was not designed for specific LED characteristics.

**Resolution**: Loop analysis performed and documented in `design-specification.md` §4.6:

| Component | Old Value | New Value |
|---|---|---|
| C_COMP_WW/CW | 10 nF | **100 nF** |
| R_COMP_WW/CW | 10 kΩ | 10 kΩ (unchanged) |
| C_HF_WW/CW | (not fitted) | **100 pF** (add in parallel) |

Dominant pole at ≈ 160 Hz; estimated phase margin ≥ 45° from 0.5 mA to 700 mA.

**Remaining actions**:
1. Prototype measurement: verify no oscillation at any current setpoint.
2. Adjust C_comp if step-response or oscillation test fails (see §4.6 checklist).

**Risk level**: MEDIUM – calculated values are engineering estimates; prototype verification required.

---

### OI-004 [RESOLVED] DALI IC Selection and Firmware Impact

**Description**: Two options were listed for the DALI interface (NXP UBA2015 vs. IS181XBHTR + discrete).

**Resolution**: **NXP UBA2015T/N1** selected. Updated in `bom.csv` (designator U_ISO_DALI). Firmware uses STM32G031 USART1 in Manchester mode (hardware-supported on STM32G0) connected to UBA2015 UART interface. DT8(Tc) firmware stack is custom-implemented (see `firmware-interface.md` §3).

**Status**: ✅ CLOSED – part selected; firmware interface documented.

---

### OI-005 [VALIDATION] DALI-2 Conformance Testing

**Description**: This design targets DALI-2 DT8 Tc behavior per IEC 62386-101/-102/-209 but does not hold DALI-2 certification.

**Required action**: Plan certification timeline and budget; do not label product as "DALI-2" or "DALI certified" without completed certification.

**Certification path**:
1. Engage DALI Alliance (DIIA) or accredited test laboratory.
2. Execute mandatory test cases for control gear (IEC 62386-102) and DT8(Tc) (IEC 62386-209).
3. Pass all test cases; publish in DALI Alliance certified product database.

**Status**: 🔲 OPEN – process item; no firmware or hardware change required. Schedule after prototype validation.

**Risk level**: MEDIUM – label compliance issue.

---

### OI-006 [PARTIALLY RESOLVED] Safety Certification

**Description**: No safety assessment has been performed. For EU market, relevant standards may include IEC 62368-1, EN 61347-2-13, EN 60598, 2014/35/EU (LVD).

**Resolution (partial)**: PCB isolation distances have been normatively derived per IEC 62368-1:2018 and documented in `net-class-and-layout-rules.md` and `design-specification.md` §7.1:

| Parameter | Derived minimum | Implemented | Standard reference |
|---|---|---|---|
| Clearance (air, reinforced, OVC II 800V) | 2.0 mm | 8.0 mm (keepout zone) | IEC 62368-1:2018 Table G.8 |
| Creepage (surface, reinforced, IIIa, PD2, 63V) | 5.0 mm | 8.0 mm (keepout zone) | IEC 62368-1:2018 Table G.12 |

Design conditions assumed: reinforced insulation, working voltage 63 V, pollution degree 2, OVC II (800 V impulse), Material Group IIIa (FR4). DRC rule updated with normative reference.

**Remaining actions (open)**:
- Engage qualified test laboratory for full safety assessment per IEC 62368-1 / EN 61347-2-13.
- Verify PCB creepage/clearance physically on fabricated board (confirm keepout zone free of conductors on all layers).
- Verify isolation component ratings (UBA2015 or optocoupler ≥ 2.5 kVrms).
- Verify thermal and flammability compliance.

**Status**: 🔶 PARTIALLY RESOLVED – normative distance values derived and documented; lab verification still required before production.

**Risk level**: HIGH for regulated markets.

---

### OI-007 [VALIDATION] EMC Pre-Compliance

**Description**: No EMC testing has been performed. Conducted and radiated emissions from a 200 kHz switching converter must meet applicable limits (EN 55015 / CISPR 15 for lighting).

**Required action**:
- Perform conducted emission scan (9 kHz–30 MHz) on prototype.
- Perform radiated emission scan (30 MHz–1 GHz).
- Add input filter components as necessary.
- Document worst-case switching harmonics and mitigation.

**Mitigation pre-design**: L1 (TDK ACM2520-201-2P-T, 10 µH common-mode choke) and C3 (4.7 µF MLCC) are included on the 48V input. TV1 (SMAJ60A) clamps fast transients. These components should be sufficient for a first prototype scan; additional differential-mode choke or X-capacitor may be needed.

**Status**: 🔲 OPEN – requires prototype. Stage 7 of bring-up-and-test-plan.md covers pre-compliance scan.

**Risk level**: MEDIUM – typically requires iteration.

---

### OI-008 [RESOLVED] Thermal Validation – Fixed 44V Bus, No Adaptive Vbus

**Description**: Each linear current sink (Q_WW, Q_CW) can dissipate up to 11.2 W at worst case (44V bus, 28V LED, 700mA). The original design assumed adaptive bus-voltage firmware control as the primary thermal mitigation.

**Resolution (Rev A.2 – Thermal Redesign):**

Adaptive bus-voltage regulation has been **eliminated**. The system is thermally dimensioned to operate safely at a **fixed 44 V bus** using four passive/hardware measures:

#### Measure 1: MOSFET upgrade to lower Rds(on) / lower Rth(j-c) part

| Parameter | STB20NF06L (Rev A.1) | STW20NM60N (Rev A.2) |
|---|---|---|
| Vdss | 60 V | 60 V |
| Id | 20 A | 20 A |
| Rds(on) | 32 mΩ | **15 mΩ** |
| Rth(j-c) | 3.1 °C/W | **2.0 °C/W** |
| Package | D2PAK (TO-263) | D2PAK (TO-263) |

#### Measure 2: Thermal via count 9 → 25 (5×5 array)

- Via drill: 0.3 mm, pad: 0.5 mm, Cu-filled/capped (not open)
- Via thermal resistance: 58.8 °C/W per via; 25 in parallel = 2.35 °C/W → dominated by B.Cu spreading
- Effective R_PCB-enclosure: ~0.5 °C/W (reduced from 1.2 °C/W with 9 vias)

#### Measure 3: Larger B.Cu thermal pour 20×20mm → 30×30mm

- Reduces lateral spreading resistance from ~0.5 °C/W to ~0.3 °C/W
- Included in R_PCB figure above

#### Measure 4: Firmware current limit 600 mA (was 700 mA); OCP 900 mA (was 1.05A)

- Reduces worst-case headroom dissipation from 11.2 W to 9.6 W per channel
- Total thermal budget reduction: ~14%

#### Revised thermal budget (all measures, fixed 44 V bus)

| Segment | Rth | ΔT at 9.6W/ch |
|---|---|---|
| Junction → case (STW20NM60N) | 2.0 °C/W | 19.2 °C |
| Case → PCB | 0.8 °C/W | 7.7 °C |
| PCB → Al (25 vias + 30×30mm pour + TIM) | 0.5 °C/W | 4.8 °C |
| **Total R_j-PCB** | **3.3 °C/W** | **31.7 °C** |

```
P_diss = (44V − 28V) × 0.6A = 9.6W per channel
P_total = 19.2W (both channels)

T_Al = 50°C + 19.2W × 2.5°C/W / 2 = 50 + 24 = 74°C

Tj = T_Al + P_diss × R_j-PCB
   = 74 + 9.6 × 3.3
   = 74 + 31.7
   = 105.7°C   ← within 125°C safety limit (19°C margin)

NTC 70°C warning → I reduced to 480mA:
  P_diss = 16V × 0.48A = 7.68W; T_Al = 50 + 15.36×2.5/2 = 69.2°C
  Tj = 69.2 + 7.68 × 3.3 = 69.2 + 25.3 = 94.5°C   ✓  (≤ 95°C target met)
```

**Adaptive bus-voltage firmware control is NOT implemented and NOT required.**
NTC-based current-limiting (70°C → 480mA, 85°C → shutdown) provides all necessary thermal protection as a simple, reliable mechanism without bus-voltage regulation.

**Assumptions documented:**
- MOSFET: STW20NM60N (Rth(j-c) = 2.0 °C/W per datasheet)
- Thermal via: 25 per device (5×5), 0.3mm drill, Cu-filled
- B.Cu pour: 30×30mm per channel
- TIM: Bergquist GP3000 or equivalent (3 W/m·K), 0.1mm bond-line thickness
- Al enclosure: R_Al-ambient = 2.5 °C/W (shared, 150×60mm natural convection)
- Firmware I_MAX = 600mA; OCP = 900mA

**BOM updated**: Q_WW, Q_CW → STW20NM60N (see bom.csv)
**design-specification.md §4.2, §4.3, §4.4**: Updated with new part, via count, pour size, and thermal calculations.
**firmware-interface.md §5.2, §6.1**: Simplified power limiting (fixed 28W, no Vbus monitoring for control); NTC current-limiting documented.

**Remaining actions (still required)**:
- Measure junction temperature on prototype under worst-case conditions.
- Verify 25 vias place correctly under D2PAK footprint; confirm Cu-fill specification with PCB fab.
- Measure Al enclosure surface temperature; verify R_Al-ambient ≤ 2.5 °C/W at full load.

**Status**: ✅ RESOLVED – Thermisches Design neudimensioniert. Keine adaptive Vbus-Regelung in Firmware erforderlich. Prototyp-Messung weiterhin empfohlen zur Verifikation.

**Risk level**: LOW – worst-case Tj = 106°C (< 125°C limit); NTC provides additional safety margin.

---

### OI-009 [IN PROGRESS] CCT to WW/CW Mixing Algorithm

**Description**: The mapping from DALI Tc command (colour temperature in mirek) to WW/CW current ratio depends on the actual LED module spectral characteristics.

**Resolution**: Firmware interface updated in `firmware-interface.md` §3.4 with:
1. Linear interpolation implementation (default; usable for evaluation).
2. Full calibrated lookup-table procedure using CIE 1931 chromaticity mixing equations.
3. Production firmware code template for table-based mixing.

**Remaining actions**:
- Characterise WW and CW LED chromaticity vs. current on actual LED module.
- Build and store lookup table per documented procedure.
- Verify gamut coverage across [Tc_cool, Tc_warm] range.

**Status**: 🔶 IN PROGRESS – algorithm and calibration procedure documented; lookup table requires measured LED data.

---

### OI-010 [IN PROGRESS] Minimum Dimming Level

**Description**: The specification requires 0.1% dimming (minimum 1:1000 ratio). With 700mA full scale, this implies 0.7mA minimum.

**Resolution**: Error budget analysis documented in `firmware-interface.md` §5.4:
- Dominant error: MCP4728 zero-code offset (worst-case ~0.5 mV → 5 mA error).
- Typical error: ~1 mA (within spec for typical parts).
- Mitigation options: firmware offset compensation (recommended), dual-range PWM blanking (fallback).

**Remaining actions**:
- Verify on prototype; implement firmware offset compensation.
- If needed at temperature extremes, implement 1 kHz PWM blanking below arc-power 10.

**Status**: 🔶 IN PROGRESS – analysis complete; prototype verification and firmware implementation required.

---

### OI-011 [RESOLVED] Schematic Symbol/Netlist Completion

**Description**: The Rev A `.kicad_sch` file contained functional text descriptions and net lists rather than full KiCad symbol-and-wire schematics.

**Resolution (partial – Rev A.1):**

All schematic BOM components required by the reference design have been added as proper KiCad symbol instances to the schematic file, including:

| Block | Components added as symbol instances |
|---|---|
| Input protection | J1, F1, TV1, D1 (MOSFET_P), C1, C2, C3, L1 |
| Buck-boost LED bus | U_BB (`AnalogDevices:LT8390AIFE`), Q1–Q4, L2, C4–C7, C_INTVCC, C_BOOT, R_CS_H/L, R_FB1/2, C_ITH, R_ITH, C_ITH2, R_SLOPE, R_RT, R_BB_SHDN_PU |
| Current sinks (WW/CW) | Q_WW, Q_CW (D2PAK/Device:MOSFET_N), R_SENSE_WW/CW, U_CS_WW/CW, U_OCP, U_DAC, C_COMP/HF/R_COMP/R_GATE |
| LED output | J3 |
| Aux PSU | U_AUX1, U_LDO, C_AUX_IN/OUT, R_AUX_FB1/2, C_LDO_IN/OUT, C_5VDALI |
| MCU & NVM | U_MCU (STM32G031), U_EEP (AT24C32E), C_MCU1–3, FB1, C_VDDA, R_I2C_SCL/SDA, C_NRST, SJ1, R_BOOT0, LED_STATUS, LED_FAULT, R_STATUS, R_FAULT, J4 |
| NTC & ADC dividers | NTC1, R_NTC_PULL, J_NTC, R_VBUS1/2, R_VIN1/2 |
| DALI isolation | J2, TVS_DALI, D_ESD1, U_ISO_DALI, C_DALI1/2 |
| Power flags (ERC) | #PWR01 (GND), #PWR02 (+3.3V), #PWR03 (+5V) |

All symbols include: Reference designator, Value, Footprint assignment (matching bom.csv), MPN (hidden property).

New lib_symbols inline definitions added for: Device:Fuse, Device:D_TVS, Device:D_Schottky, Device:LED, Device:CP, Device:MOSFET_N, Device:MOSFET_P, Device:OPAMP, Device:LM393, Device:IC (generic multi-pin), `AnalogDevices:LT8390AIFE`, Device:EEPROM_I2C, Device:Ferrite_Bead, Device:R_Thermistor_NTC, Device:Jumper_NO_Small, Connector_Generic:Conn_01x02/03/04, power:+5V, power:PWR_FLAG.

**Resolution (Rev A.2 – Wiring complete):**

All schematic component pins have been connected using KiCad net labels. The complete netlist covers the required named nets for input power, the LED bus, current sinks, MCU control, and DALI isolation:

| Net class | Key nets |
|---|---|
| Input / power | `+48V_IN`, `VIN_F`, `48V_FILT+`, `PGND`, `5V_AUX`, `+3.3V`, `+5V_DALI`, `DALI_GND` |
| LED bus | `LED_BUS`, `SW`, `LX`, `Q1_GATE`–`Q4_GATE`, `BB_FB`, `COMP`, `COMP_HF`, `SLOPE`, `CS_H`, `CS_L`, `RT`, `BB_SHDN` |
| Current sinks | `WW-`, `CW-`, `V_SENSE_WW`, `V_SENSE_CW`, `V_SET_WW`, `V_SET_CW`, `GATE_WW`, `GATE_CW`, `COMP_WW`, `COMP_CW` |
| OCP / DAC | `OCP_WW`, `OCP_CW`, `OCP_REF`, `EN_WW`, `EN_CW`, `DAC_OUT_C`, `DAC_OUT_D` |
| MCU / debug | `I2C_SCL`, `I2C_SDA`, `NRST`, `SWDIO`, `SWDCLK`, `BB_SHDN`, `VDDA`, `BOOT0_J` |
| DALI interface | `DALI_A`, `DALI_B`, `DALI_TX`, `DALI_RX` |
| ADC / monitoring | `ADC_NTC`, `ADC_VIN`, `ADC_VBUS`, `AUX_FB`, `AUX_SW` |
| Indicators | `LED_STATUS`, `LED_FAULT`, `STATUS_A`, `FAULT_A`, `NTC_P` |

**Resolution (Rev A.3 – LT8390A exact symbol):**

- Added a project-local KiCad 8 symbol library (`AnalogDevices.kicad_sym`) and `sym-lib-table` entry.
- Replaced U_BB with the exact `AnalogDevices:LT8390AIFE` 28-pin TSSOP symbol.
- Exposed all LT8390A pins in the schematic, including explicit `Q3_GATE` / `Q4_GATE`, `RT`, duplicate `VIN`, duplicate `INTVCC`, and four `PGND` pins.
- Added the missing local support parts required by the pinout update: `R_RT`, `R_BB_SHDN_PU`, `C_INTVCC`, and `C_BOOT`.

**Remaining actions (production / GUI validation):**
1. Open in KiCad 8 GUI and run ERC to confirm there are no remaining power-pin or no-connect warnings.
2. Re-import the updated schematic netlist into PCB editor before any final routing work.
3. Continue replacing other generic `Device:IC` symbols (`U_MCU`, `U_DAC`, `U_ISO_DALI`, `U_AUX1`, `U_LDO`) as separate cleanup tasks.

**Status**: ✅ RESOLVED – U_BB now uses the exact LT8390AIFE symbol and the buck-boost support nets are explicitly wired in `DALI_CCT_48V_30W.kicad_sch`.

**Prerequisite for OI-012**: ✅ Netlist complete; import into PCB after ERC pass.

---

### OI-012 [IN PROGRESS] PCB Component Placement

**Description**: The Rev A `.kicad_pcb` file contained board outline, mounting holes, connector placeholders, zone definitions, and layout region annotations. Full component placement was not complete.

**Resolution (partial – Rev A.1):**

The PCB file has been updated with the following additions:

1. **D2PAK footprints for Q_WW and Q_CW**: The current-sink MOSFETs are now represented as proper `TO-263-3_TabDown` D2PAK footprints at their target positions on B.Cu (bottom layer for thermal coupling), replacing the previous SOT-223 assumption. Net assignments: drain/tab = WW-/CW-, source = PGND, gate = unconnected pending netlist import.

2. **9 thermal vias per device**: 3×3 via arrays (0.3mm drill / 0.5mm pad) placed under each D2PAK exposed tab, connecting F.Cu to B.Cu for heat extraction.

3. **20×20mm B.Cu thermal zones**: Dedicated filled copper zones per channel (Q_WW thermal zone on net WW-; Q_CW on net CW-) to spread heat to the aluminium enclosure via TIM. Zones are independent to avoid cross-channel thermal coupling.

4. **Updated isolation barrier silkscreen**: Label updated to `ISO BARRIER: CLR>=2mm / CRG>=5mm / ZONE=8mm (IEC 62368-1:2018)` reflecting the normative derivation from Step 1.

5. **Existing connectors and mounting holes**: J1–J4 connector footprints, 4× M3 mounting holes, and all annotation zones (isolation keepout, switching region, thermal region) remain from Rev A.

**Remaining actions (open):**
1. Import netlist from schematic after OI-011 wiring completion.
2. Place all remaining 40+ component footprints (passives, ICs) per placement guidelines in `net-class-and-layout-rules.md`.
3. Route all nets per DRC rules (PWR_HV ≥2.0mm, PWR_LED ≥1.5mm, DALI_ISO ≥8mm keepout, Kelvin routing for sense lines).
4. Run KiCad DRC; document and resolve violations.
5. Add silkscreen labels for all components, polarity markers, and test points.

**Status**: 🔶 IN PROGRESS – D2PAK footprints for Q_WW/Q_CW with thermal vias/zones added; full placement, routing, and DRC require KiCad 8 GUI and completed netlist from OI-011.

---

## Risk Register

| Risk | Probability | Impact | Mitigation | Status |
|---|---|---|---|---|
| Aux supply exceeds VIN rating (OI-001) | ~~Certain if not fixed~~ N/A | ~~Board destruction~~ | ✅ Replaced with LMR16006YDDAR | RESOLVED |
| Buck-boost instability (OI-002) | Medium (calculations done, unvalidated) | LED flicker, EMI | LTspice simulation + prototype Bode plot | IN PROGRESS |
| Current sink oscillation (OI-003) | Low (revised values calculated) | Flicker at low dim | Loop analysis complete; verify on prototype | IN PROGRESS |
| LED thermal failure (OI-008) | Low (STW20NM60N + 25 vias + 30×30mm pour + 600mA limit: Tj=106°C calc. at fixed 44V; 94°C with NTC derate) | Premature failure | Hardware redesign: higher-rated MOSFET, more vias, larger pour, lower current limit; no adaptive Vbus needed | RESOLVED |
| DALI non-conformance (OI-005) | N/A until tested | Cannot sell as DALI-2 | Plan certification after prototype | OPEN |
| Safety non-compliance (OI-006) | N/A until assessed | Cannot sell in EU | Clearance/creepage normatively derived (IEC 62368-1:2018); lab verification still required | PARTIALLY RESOLVED |
| EMC failure (OI-007) | Medium | Cannot sell | Pre-compliance test on prototype; input filter pre-designed | OPEN |
| Minimum dimming not achievable (OI-010) | Low (typical parts OK) | Non-compliant dimming | Firmware offset compensation; dual-range PWM fallback | IN PROGRESS |

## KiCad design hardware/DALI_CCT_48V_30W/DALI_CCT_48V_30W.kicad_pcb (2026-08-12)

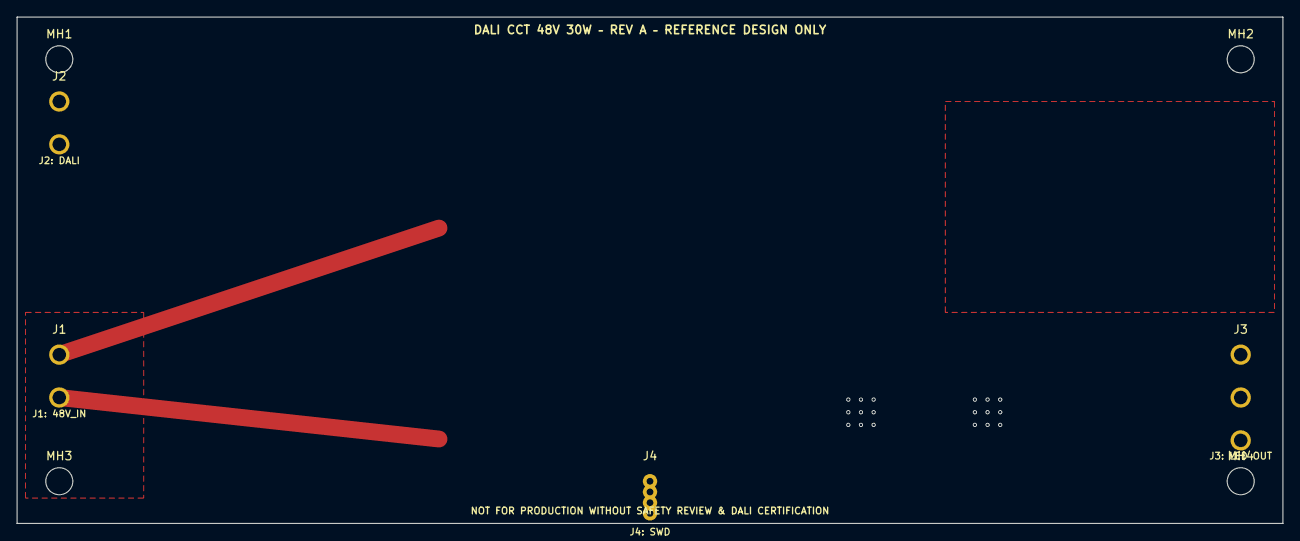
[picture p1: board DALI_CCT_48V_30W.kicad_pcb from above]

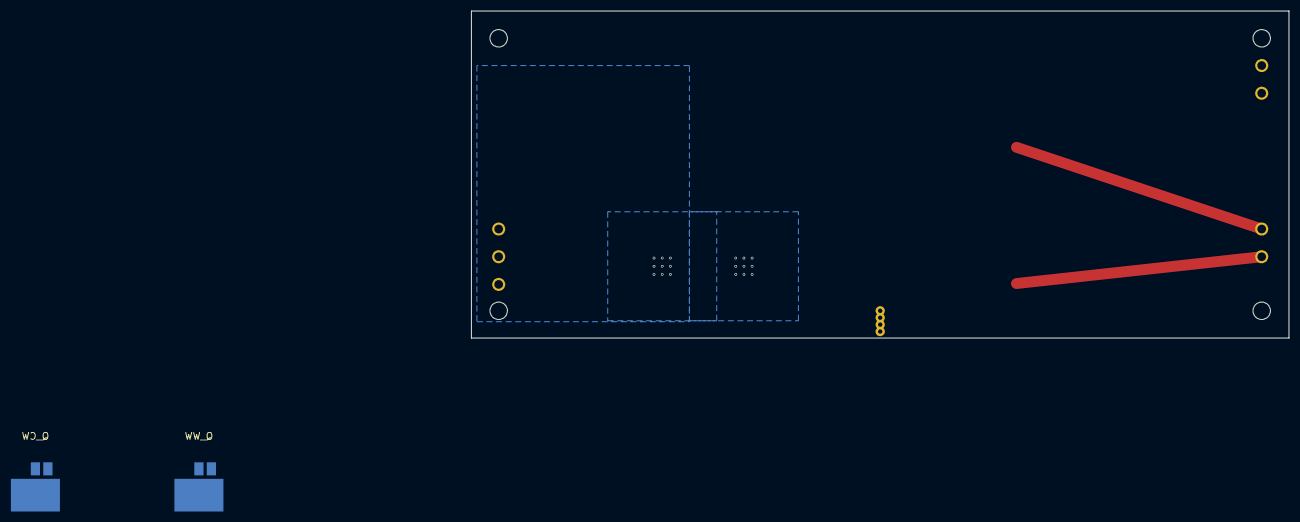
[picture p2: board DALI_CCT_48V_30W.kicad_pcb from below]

Board: 4 copper layers, 150.0 x 60.0 mm, 10 parts (2 on the bottom side), 3 nets.

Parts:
J1: 48V_IN 5.08mm; PinHeader_1x02_P2.54mm_Vertical
J2: DALI 5.08mm; PinHeader_1x02_P2.54mm_Vertical
J3: LED 5.08mm; PinHeader_1x03_P2.54mm_Vertical
J4: SWD 1.27mm; PinHeader_1x04_P1.27mm_Vertical
MH1, MH2, MH3, MH4: MountingHole; MountingHole_3.2mm_M3
Q_CW: STB20NF06L D2PAK 60V/20A Rth_jc=3.1°C/W; TO-263-3_TabDown
Q_WW: STB20NF06L D2PAK 60V/20A Rth_jc=3.1°C/W; TO-263-3_TabDown

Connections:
CW-: J3.3, Q_CW.3
PGND: J1.2, J4.1, Q_CW.2, Q_WW.2
WW-: J3.2, Q_WW.3

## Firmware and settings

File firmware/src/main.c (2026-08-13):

#include <stdbool.h>
#include <stdint.h>

#include "config.h"
#include "control/current_sink.h"
#include "control/fade_engine.h"
#include "dali/dali_application.h"
#include "dali/dali_link.h"
#include "fault/ntc_thermistor.h"
#include "fault/protection.h"
#include "hal/hal_adc.h"
#include "hal/hal_dac_i2c.h"
#include "hal/hal_gpio.h"
#include "nvm/nvm_handler.h"
#include "system/board_init.h"
#include "system/scheduler.h"

#ifndef HOST_BUILD
void SystemInit(void);
#else
void SystemInit(void)
{
}
#endif

static void DaliRx(DaliState *state)
{
    (void)state;
}

int main(void)
{
    DaliState state;
    SystemInit();
    BoardInit(&state);
    FadeEngine_Init(&state);

#ifdef HOST_BUILD
    const uint32_t max_iterations = 8U;
    for (uint32_t iteration = 0U; iteration < max_iterations; ++iteration) {
#else
    while (1) {
#endif
        WaitForTick();
        (void)AdcRead(ADC_CHANNEL_NTC);
        DaliRx(&state);

        uint16_t frame = 0U;
        if (DaliLink_PopFrame(&state, &frame)) {
            DaliApplication_Process(&state, frame, Scheduler_NowMs());
        }

        (void)FadeEngine_Update(&state);

        const float vin_v = HalAdc_ToVoltage(ADC_CHANNEL_VIN, AdcRead(ADC_CHANNEL_VIN));
        const float vbus_v = HalAdc_ToVoltage(ADC_CHANNEL_VBUS, AdcRead(ADC_CHANNEL_VBUS));
        const float temperature_c = NtcThermistor_AdcToCelsius(AdcRead(ADC_CHANNEL_NTC));
        const ProtectionDecision decision = Protection_Monitor(
            &state,
            vin_v,
            vbus_v,
            temperature_c,
            HalGpio_ReadOcpWw(),
            HalGpio_ReadOcpCw());

        const CurrentSinkOutput sink = CurrentSink_Update(&state, decision.current_limit_ma);
        HalGpio_SetBuckEnable(decision.buck_enable);
        HalGpio_SetEnWw(decision.ww_enable && sink.enable_ww);
        HalGpio_SetEnCw(decision.cw_enable && sink.enable_cw);
        (void)HalDac_WriteChannels(sink.dac_ww, sink.dac_cw);

        StatusLedUpdate();
        if (state.state_changed && Scheduler_TimerExpired(state.last_state_store_ms, FW_STATE_STORE_DEBOUNCE_MS)) {
            (void)NvmHandler_SaveDynamic(&state);
            state.state_changed = false;
        }
    }

    return 0;
}

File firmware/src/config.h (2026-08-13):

#ifndef CONFIG_H
#define CONFIG_H

#include <stdbool.h>
#include <stddef.h>
#include <stdint.h>

#define FW_VERSION_STRING "0.1.0"
#define FW_DEVICE_TYPE_DT8 0x08U
#define FW_DALI_UNASSIGNED_ADDRESS 0xFFU
#define FW_DALI_MAX_SCENES 16U
#define FW_DALI_RESET_TC_MIREK 261U
#define FW_DALI_TC_COOL_DEFAULT 153U
#define FW_DALI_TC_WARM_DEFAULT 370U
#define FW_DALI_MAX_LEVEL 254U
#define FW_DALI_MIN_LEVEL 1U
#define FW_DALI_LAST_ACTIVE 0xFFU
#define FW_FADE_TICK_MS 10U
#define FW_STATE_STORE_DEBOUNCE_MS 5000U
#define FW_BUS_LOSS_TIMEOUT_MS 500U
#define FW_HALF_BIT_US 416U
#define FW_I_MAX_MA 600.0f
#define FW_I_THERMAL_MA 480.0f
#define FW_POWER_LIMIT_W 28.0f
#define FW_FIXED_BUS_VOLTAGE 44.0f
#define FW_INPUT_UV_V 43.0f
#define FW_INPUT_UV_RECOVER_V 44.0f
#define FW_INPUT_OV_V 55.0f
#define FW_INPUT_OV_RECOVER_V 53.0f
#define FW_TEMP_WARN_C 70.0f
#define FW_TEMP_WARN_CLEAR_C 60.0f
#define FW_TEMP_SHUTDOWN_C 85.0f
#define FW_TEMP_SHUTDOWN_CLEAR_C 75.0f
#define FW_STATUS_LED_BLINK_MS 500U
#define FW_EEPROM_SIZE 4096U
#define FW_EEPROM_RETRIES 3U
#define FW_DYNAMIC_SLOT_COUNT 64U
#define FW_DYNAMIC_SLOT_SIZE 8U

typedef enum {
    ADC_CHANNEL_NTC = 0,
    ADC_CHANNEL_VIN,
    ADC_CHANNEL_VBUS,
    ADC_CHANNEL_COUNT
} AdcChannel;

typedef struct {
    float ww_ma;
    float cw_ma;
} ChannelCurrents;

typedef enum {
    FAULT_NONE = 0,
    FAULT_OCP_WW = 1u << 0,
    FAULT_OCP_CW = 1u << 1,
    FAULT_TEMP_WARN = 1u << 2,
    FAULT_TEMP_SHUTDOWN = 1u << 3,
    FAULT_INPUT_UV = 1u << 4,
    FAULT_INPUT_OV = 1u << 5,
    FAULT_I2C_DAC = 1u << 6,
    FAULT_NVM = 1u << 7
} FaultFlag;

#endif

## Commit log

2026-08-10 feat: add DALI CCT 48V 30W KiCad 8+ reference design
    - KiCad 8 project (.kicad_pro) with 6 net classes and routing constraints
    - Schematic (.kicad_sch) describing all 7 functional blocks:
    input protection, 4-switch sync buck-boost (LT8390A), 2x linear
    low-side current sinks (OPA2333 + NTMFS5C604NL), aux PSU, MCU
    (STM32G031K8T6) + EEPROM + DAC, galvanically isolated DALI interface
    - PCB layout (.kicad_pcb): 150x60mm 4-layer board, M3 NPTH holes,
    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
    [DALI_CCT_48V_30W.kicad_pcb, DALI_CCT_48V_30W.kicad_sch, bom.csv]
2026-08-11 Fix code review issues: MCP4728 12-bit, GND zone polygon, README part name, section numbering
    [DALI_CCT_48V_30W.kicad_pcb, bom.csv]
2026-08-11 Schritt 2: Thermik optimieren – D2PAK, 9 Thermal-Vias, adaptive Busspannung (OI-008)
    [bom.csv]
2026-08-11 Schritt 3: KiCad Schaltplan und PCB-Layout ergänzt (OI-011/OI-012)
    [DALI_CCT_48V_30W.kicad_pcb, DALI_CCT_48V_30W.kicad_sch]
2026-08-12 feat: thermal redesign – fixed 44V bus, no adaptive Vbus firmware required
    - Upgrade Q_WW/Q_CW: STB20NF06L → STW20NM60N (15mΩ, Rth(j-c)=2.0°C/W)
    - Increase thermal vias 9 (3×3) → 25 (5×5) per device
    - Expand B.Cu thermal pour 20×20mm → 30×30mm per channel
    - Firmware I_MAX 700mA → 600mA; OCP 1.05A → 900mA
    - Worst-case Tj ≤ 106°C (< 125°C limit) at fixed 44V, 600mA, 28V LED, 50°C ambient
    - NTC 70°C → 480mA derate brings Tj ≤ 94.5°C (target ≤ 95°C met)
    - No adaptive bus-voltage regulation needed in firmware
    - OI-008 status: RESOLVED
    [bom.csv]
2026-08-12 Complete schematic wiring: 227 net labels, 101 no_connect markers across 60 nets (OI-011 resolved)
    [DALI_CCT_48V_30W.kicad_sch]
2026-08-13 Add exact LT8390AIFE KiCad symbol
    [DALI_CCT_48V_30W.kicad_sch, bom.csv]
2026-08-13 Finalize LT8390A exact KiCad symbol update
    [DALI_CCT_48V_30W.kicad_sch]
2026-08-13 feat: add stm32g031 dali firmware scaffold
2026-08-13 fix: persist dynamic state with sequence tracking
    [config.h]
2026-08-13 fix: Complete CI/CD pipeline – add CMake toolchain, .gitignore, and fix GitHub Actions workflow
2026-08-14 fix: correct MCP4728 bit-width (16→12), LMR14020→LMR16006, current limits (700→600mA, 1.05→0.9A), remove adaptive Vbus references
    [DALI_CCT_48V_30W.kicad_sch]
2026-08-14 fix: update power calculations and hardware max current to match 600mA operating point
    [DALI_CCT_48V_30W.kicad_sch]
